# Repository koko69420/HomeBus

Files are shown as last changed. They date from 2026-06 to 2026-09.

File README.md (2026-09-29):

<p align="center">
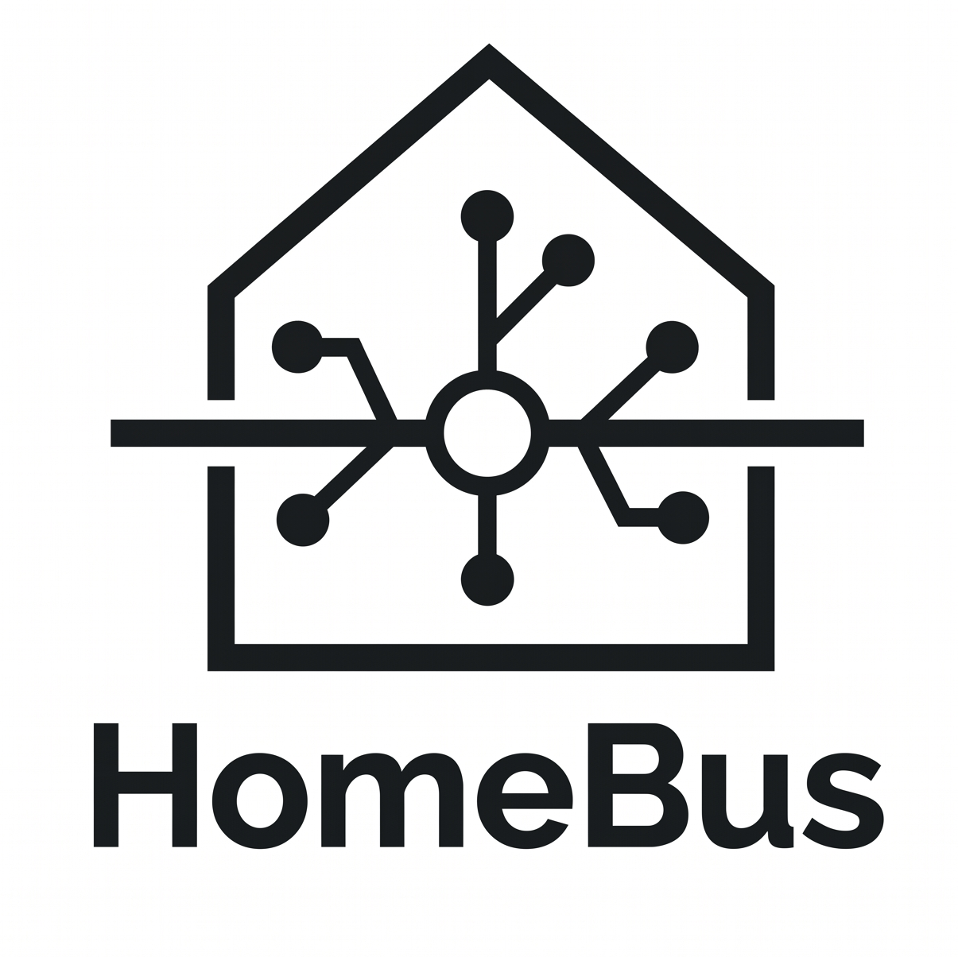
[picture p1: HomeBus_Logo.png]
HomeBus Logo
  
</p>

<h1 align="center">HomeBus</h1>

<p align="center">
  <strong>A deterministic, hard-wired distributed home automation platform built on 32-bit RISC-V microcontrollers, full-duplex RS-422 differential networking, centralized 24V DC power distribution, and native Home Assistant integration.</strong>
</p>

<p align="center">
  <a href="#system-architecture">Architecture</a> •
  <a href="#hierarchical-documentation">Documentation Map</a> •
  <a href="#hardware-overview">Hardware</a> •
  <a href="#protocol--firmware">Protocol & Firmware</a> •
  <a href="#repository-structure">Repository Structure</a> •
  <a href="#getting-started--toolchain">Getting Started</a>
</p>

---

## Overview & Motivation

Modern smart homes face severe reliability degradation when relying on congested 2.4 GHz wireless networks (Wi-Fi, Zigbee, Bluetooth). RF interference, wireless mesh packet dropouts, battery maintenance for wall sensors, and high-latency cloud dependencies undermine home automation dependability.

**HomeBus** solves this by delivering an industrial-grade, hard-wired residential infrastructure:
- **Full-Duplex RS-422 Differential Signaling**: Non-blocking serial communications operating at high baud rates without bus collision arbitration.
- **Centralized 24V DC Power Distribution**: Power and high-speed data are distributed over a single multi-conductor cable (CAT5e), eliminating failure-prone miniature AC-DC supplies inside cramped wall flush boxes.
- **Hardware/Logical Decoupling**: Wall switches trigger 32-bit logical device endpoints (`0xRRTTDDDD`). Physical hardware nodes (identified via 8-bit DIP switches) can be re-routed, replaced, or bridged to third-party devices (such as Tuya or Zigbee) without modifying wall switch wiring or node code.
- **Room-Level Gateway Segmentation**: Dual-transceiver gateway nodes divide the physical network into isolated room segments, insulating the central backbone from local switch traffic and safeguarding against bus-wide faults.
- **Fail-Safe Dual-Slot OTA Updates**: Permanent bootloader with ping-pong application flash partitions and automatic health verification rollbacks.

---

## System Architecture

```mermaid
flowchart TD
    subgraph Central ["Central Controller & Power Supply"]
        HA["Home Assistant Controller\n(Logical Address: 0xFFFF)\nMQTT / HomeBus Integration"]
        PSU["Central 24V 5A Industrial SMPS\n(DIN-Rail Mounted)"]
    end

    subgraph Backbone ["Backbone Bus (24V DC + RS-422 Full-Duplex)"]
        GW1["Gateway Node — Room 1\n(Dual MAX491 + EEPROM)"]
        GW2["Gateway Node — Room 2\n(Dual MAX491 + EEPROM)"]
    end

    subgraph Room1 ["Room 1 Sub-Bus (Isolated RS-422 + 24V Rail)"]
        BN1["Base Node\n(In-Wall Relays & Wall Switches)"]
        FN1["Fan Controller Node\n(AC Phase Control & Current Sense)"]
        SN1["Auxiliary Sensor Daughterboard\n(Presence / Temp / Lux)"]
    end

    subgraph Room2 ["Room 2 Sub-Bus (Isolated RS-422 + 24V Rail)"]
        BN2["Base Node\n(Multi-Channel Relay Actuator)"]
        FN2["Fan Controller Node\n(Ceiling Fan Speed)"]
    end

    HA <-->|RS-422 Backbone| GW1
    HA <-->|RS-422 Backbone| GW2
    PSU -->|24V Power Bus| GW1
    PSU -->|24V Power Bus| GW2

    GW1 <-->|Isolated Sub-Bus| BN1
    GW1 <-->|Isolated Sub-Bus| FN1
    GW1 <-->|Isolated Sub-Bus| SN1

    GW2 <-->|Isolated Sub-Bus| BN2
    GW2 <-->|Isolated Sub-Bus| FN2
```

---

## Hierarchical Documentation

The HomeBus documentation is hierarchically organized to provide deep technical detail at every layer while maintaining clean separation of concerns:

```text
README.md (Master Root)
├── Hardware/README.md (Hardware Subsystem Overview)
│   ├── base_node/README.md (In-Wall Actuator & Switch Interface)
│   ├── Gateway_node/README.md (Dual-Transceiver Room Segmentation Router)
│   ├── Fan_Controller_node/README.md (AC Phase-Angle Fan Speed Controller)
│   └── Expanders/README.md (Prototyping Adapters & Footprint Breakouts)
└── Firmware/README.md (Firmware & Protocol Specification v0.1)
```

### Direct Documentation Links

| Layer | Subsystem / Component | Key Documentation Topics | Link |
| :--- | :--- | :--- | :--- |
| **Subsystem** | **Hardware Platform** | 24V Bus power distribution, RS-422 differential signaling, SM712 surge protection, complete Bill of Materials (BOM), KiCad custom symbol & footprint libraries. | [Hardware Subsystem Overview](Hardware/README.md) |
| **Component** | **Base Node** | In-wall multi-channel relay actuator, 74HC165 switch shift register, CH32X033 TSSOP-20 pinouts (Dev vs Prod), 3D production renders, manufacturing schematics. | [Base Node README](Hardware/base_node/README.md) |
| **Component** | **Gateway Node** | Dual MAX491 transceivers, CAT24C256 I2C EEPROM routing tables, traffic monitoring LEDs, dedicated development breakout board. | [Gateway Node README](Hardware/Gateway_node/README.md) |
| **Component** | **Fan Controller Node** | H11AA1 zero-crossing detection, HCPL-3120 isolated gate drive, B2415S isolated DC-DC, KIA7N65H solid-state AC switching, active stall threshold protection. | [Fan Controller README](Hardware/Fan_Controller_node/README.md) |
| **Component** | **Expanders** | SMD prototyping daughterboards converting SOIC-14 (MAX491), SOIC-16 (74HC165), and TSSOP-20 (CH32X033) to standard 2.54 mm breadboard headers. | [Expanders README](Hardware/Expanders/README.md) |
| **Subsystem** | **Firmware & Protocol** | 32-bit Logical Device Addresses (`0xRRTTDDDD`), 8-bit Physical Node IDs, Control and Telemetry packet structures, Sensor Types, dual-slot ping-pong OTA bootloader. | [Firmware & Protocol README](Firmware/README.md) |

---

## Hardware Overview

### Base Node Production Renders

| Front View (Component Layout) | Back View (Connector & Power Rail) |
| :---: | :---: |
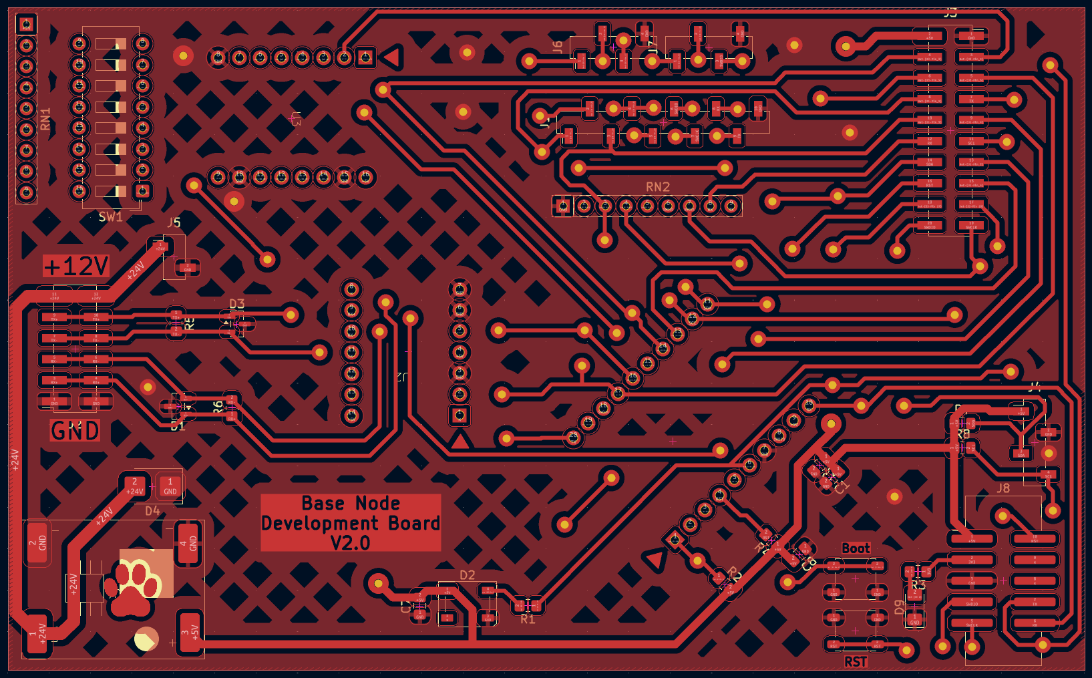
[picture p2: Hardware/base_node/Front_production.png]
HomeBus Base Node Front
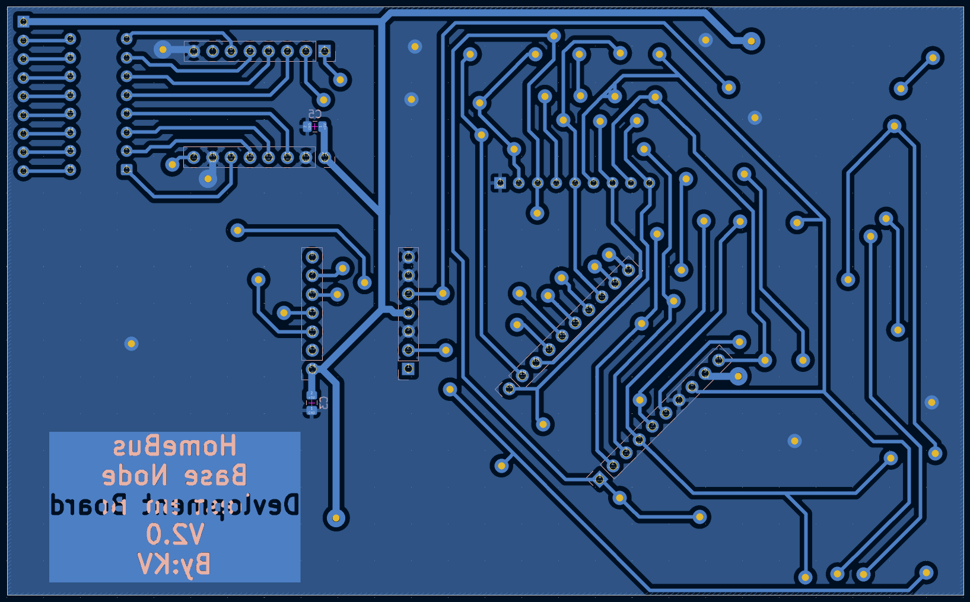
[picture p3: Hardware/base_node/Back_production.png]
HomeBus Base Node Back
|  |  |

### Core Hardware Specifications
- **Processing Core**: WCH `CH32X033F8P6` (32-bit QingKe RISC-V V4C core @ 48 MHz, 62 KB Flash, 20 KB SRAM).
- **Physical Layer Transceiver**: Maxim `MAX491CSD` / `MAX491ESD` (SOP-14 full-duplex differential transceiver).
- **Bus Power Regulation**: Monolithic Power Systems `MP1584EN` (high-frequency buck converter, 24V In to 5V DC Out @ 3A).
- **Transient Protection**: ProTek `SM712` asymmetrical bidirectional TVS diode array (-7V to +12V) on all RS-422 differential pairs.
- **Input Multiplexing**: NXP / TI `74HC165D` 8-bit PISO shift register for parallel sampling of physical wall switches and the 8-bit DIP switch.
- **Visual Feedback**: Xinglight `XL-1010RGBC` (`WS2812B-1010`) addressable RGB LED for link status and diagnostics.
- **Detailed Component Records**: Complete component pricing, supplier links, and quantities are tracked in [`Hardware/BOM Home automation.xlsx`](Hardware/BOM%20Home%20automation.xlsx).

---

## Protocol & Firmware Highlights

For the full technical protocol specification, see the [Firmware & Protocol Documentation](Firmware/README.md).

### Logical vs. Physical Addressing
- **Physical Node ID (8-bit)**: Set on the hardware DIP switch (1–255). Used strictly for commissioning, OTA updates, diagnostics, and telemetry.
- **Logical Device Address (32-bit)**: Structured as `0xRRTTDDDD`:
  - `RR`: Room ID (e.g. `0x01` Living Room)
  - `TT`: Device Type (e.g. `0x01` Relay, `0x04` Fan)
  - `DDDD`: Device Unique Index
  - `0xFFFF`: Home Assistant Central Controller
- *Input nodes never transmit physical node IDs—wall switches target logical devices, allowing seamless device migration and third-party bridging.*

### Dual-Slot Failsafe OTA Bootloader
Each node partitions its 62 KB flash into a permanent bootloader (8 KB), Application Slot A (24 KB), Application Slot B (24 KB), and Non-Volatile Config (8 KB). Firmware updates are verified with 16-bit CRC before switching execution slots, with automated fallback if health confirmation is not returned.

---

## Repository Structure

```text
HomeBus/
├── Datasheets/                                # Technical datasheets for all ICs and sensors
│   ├── 7N65H.PDF                              # KEC 650V 7A Power MOSFET
│   ├── CH32X035.pdf                           # WCH RISC-V Microcontroller Series
│   ├── HCPL3120.pdf                           # Broadcom High-CMR Gate Driver
│   ├── HWCT-5A(5mA).pdf                       # AC Current Transformer
│   ├── MCP6001.pdf                            # Microchip Rail-to-Rail Op-Amp
│   ├── RGB_LED_C5349936.pdf                   # XL-1010RGBC Addressable RGB LED
│   └── vo3120.pdf                             # Vishay High-Speed Optocoupler
├── Firmware/                                  # Firmware subsystem and protocol specifications
│   ├── HomeBus Protocol Specification v0.1.docx # Upstream design document
│   └── README.md                              # Complete protocol specification & packet format guide
├── Hardware/                                  # Hardware design, schematics, and layouts
│   ├── BOM Home automation.xlsx               # Comprehensive Bill of Materials with pricing & links
│   ├── Pin Allocations.xlsx                   # MCU GPIO allocation reference (Dev vs Prod)
│   ├── README.md                              # Hardware subsystem overview & bus topology
│   ├── base_node/                             # In-wall actuator & switch node PCB (Revisions 1 to 4)
│   │   ├── Basenode_gerber/                   # Industrial fabrication Gerbers and drill maps
│   │   ├── Front_production.png               # 3D PCB front render
│   │   ├── Back_production.png                # 3D PCB back render
│   │   ├── Schematic_manufacturing.pdf        # Production schematic plot
│   │   └── README.md                          # Base Node component documentation
│   ├── Gateway_node/                          # Segmentation bridge & routing node
│   │   ├── Gateway_node_dev-board/            # Prototyping development board layout & plots
│   │   └── README.md                          # Gateway Node component documentation
│   ├── Fan_Controller_node/                   # AC phase-angle fan speed controller PCB
│   │   └── README.md                          # Fan Controller Node component documentation
│   └── Expanders/                             # SMD to 2.54mm breadboard prototyping adapters
│       └── README.md                          # Expanders component documentation
├── lib/                                       # KiCad custom symbol, footprint, and 3D libraries
│   ├── 3D_models/                             # Mechanical STEP models
│   ├── HomeBus.kicad_mod/                     # Footprint library (.kicad_mod)
│   └── HomeBus.kicad_sym                      # Schematic symbol library
├── HomeBus_Logo.png                           # Raster logo asset
├── HomeBus_Logo.svg                           # Vector logo asset
└── README.md                                  # Root documentation hub
```

---

## Getting Started & Toolchain

### Hardware Design (EDA)
- **EDA Suite**: [KiCad 7.x / 8.x](https://www.kicad.org/)
- **Opening Projects**: Double-click `.kicad_pro` inside any node directory (e.g. `Hardware/base_node/base_node_clad_v2.kicad_pro`).
- **Libraries**: All custom components are pre-configured in project-relative paths pointing to `lib/HomeBus.kicad_sym` and `lib/HomeBus.kicad_mod/`.

### Firmware Development & Debugging
- **Core Architecture**: QingKe 32-bit RISC-V V4C (`rv32imac`).
- **Toolchain**: `riscv-none-elf-gcc` / MounRiver Studio / OpenOCD for WCH.
- **Hardware Debugger**: [WCH-LinkE](https://www.wch-ic.com/products/WCH-Link.html) programmer/debugger connected via 1-wire SWD (`SWDIO`, `SWCLK`, `GND`, `3V3`).

---

## License & Authorship

All hardware designs, schematics, PCB artwork, and protocol specifications are authored by **Kaustubh** (`koko69420`). All rights reserved.

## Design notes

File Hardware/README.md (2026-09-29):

# HomeBus Hardware Subsystem

The **HomeBus Hardware Subsystem** encompasses the schematics, PCB layouts, electrical interfaces, and component specifications that power the HomeBus automation platform. Built on the 32-bit RISC-V `CH32X033F8P6` microcontroller, HomeBus employs a robust wired topology combining a centralized 24V DC power rail with full-duplex RS-422 differential serial communications.

---

## Physical Bus Architecture & Power Distribution

HomeBus uses standard structured cabling (CAT5e / multi-conductor shielded cable) terminated into pluggable terminal blocks (`XY2500` 6-pin connectors):

```mermaid
flowchart LR
    subgraph PowerStation ["Central Power Supply"]
        PSU["24V 5A Industrial SMPS\n(Centralized DIN-Rail / Cabinet)"]
    end

    subgraph BusCable ["6-Conductor HomeBus Cable (CAT5e / Shielded)"]
        direction TB
        VBUS["+24V DC Power (Wire 1)"]
        GND["GND / Return (Wire 2)"]
        TXP["TX+ Differential Line (Wire 3)"]
        TXN["TX- Differential Line (Wire 4)"]
        RXP["RX+ Differential Line (Wire 5)"]
        RXN["RX- Differential Line (Wire 6)"]
    end

    subgraph Node ["Connected HomeBus Node"]
        BUCK["MP1584EN Step-Down\n(24V -> 5V Logic)"]
        TVS["SM712 TVS Array\n(-7V to +12V)"]
        XCVR["MAX491 Transceiver\n(RS-422 Full-Duplex)"]
        MCU["CH32X033F8P6\n(32-bit RISC-V Core)"]
    end

    PSU --> VBUS
    PSU --> GND
    VBUS --> BUCK --> MCU
    GND --> Node
    TXP & TXN & RXP & RXN <--> TVS <--> XCVR <--> MCU
```

### Key Electrical Principles
1. **Centralized 24V DC Distribution**: Eliminates bulky and fire-prone AC-to-DC converters inside small wall boxes. Centralizing mains power conversion inside a well-ventilated enclosure ensures high efficiency and simplified battery backup (UPS) integration.
2. **Local Buck Regulation**: Each node integrates an `MP1584EN` high-frequency switching buck module stepping down 24V DC to 5V DC at up to 3A, easily powering the MCU, RGB status LEDs, sensors, and external relay coils without thermal throttling.
3. **Full-Duplex Differential Signaling (RS-422)**: Utilizing dedicated differential pairs for transmit (`TX±`) and receive (`RX±`) driven by Maxim `MAX491` transceivers allows non-blocking, bidirectional communication.
4. **Transient & Surge Protection**: Every differential line interface is clamped by `SM712` asymmetrical TVS diodes designed specifically for RS-422 transceivers, safeguarding against electrostatic discharge (ESD up to ±15 kV) and induced power line transients.

---

## Node Modules & Component Directory

The HomeBus hardware platform is partitioned into specialized node modules:

| Module | Location | Primary Role & Description | Documentation Link |
| :--- | :--- | :--- | :--- |
| **Base Node** | [`base_node/`](base_node/) | In-wall multi-channel actuator and wall-switch sensor interface fitting standard electrical backboxes. | [Base Node README](base_node/README.md) |
| **Gateway Node** | [`Gateway_node/`](Gateway_node/) | Dual-transceiver bridge providing room-level bus segmentation, EEPROM routing tables, and traffic diagnostics. | [Gateway Node README](Gateway_node/README.md) |
| **Fan Controller Node** | [`Fan_Controller_node/`](Fan_Controller_node/) | Solid-state AC speed controller featuring zero-crossing sync (`H11AA1`), isolated gate drive (`HCPL-3120`), and stall prevention. | [Fan Controller README](Fan_Controller_node/README.md) |
| **Expanders** | [`Expanders/`](Expanders/) | Prototyping breakout adapters converting SMD footprints (SOIC-14, SOIC-16, TSSOP-20) to 2.54mm breadboard headers. | [Expanders README](Expanders/README.md) |

---

## Bill of Materials (BOM) Summary

Extracted directly from project engineering records ([`BOM Home automation.xlsx`](BOM%20Home%20automation.xlsx)):

| Category | Component Part | Package | Description | Key Specifications |
| :--- | :--- | :--- | :--- | :--- |
| **Processing** | WCH `CH32X033F8P6` | TSSOP-20 | RISC-V Microcontroller | 48 MHz QingKe V4C, 62 KB Flash, 20 KB SRAM |
| **Networking** | Maxim `MAX491CSD` / `MAX491ESD` | SOP-14 | RS-422 Transceiver | Full-duplex differential transceiver |
| **Input Expansion** | NXP / TI `74HC165D` | SOP-16 | Shift Register | 8-bit Parallel-In Serial-Out (PISO) |
| **Power Buck** | Monolithic Power `MP1584EN` | Module | Step-Down Buck Converter | 24V to 5V DC, 3A max output |
| **Bus Protection**| ProTek `SM712` / `PSM712` | SOT-23 | TVS Diode Array | Asymmetrical (-7V / +12V) RS-422 protection |
| **Status LED** | Xinglight `XL-1010RGBC` (`WS2812B`) | SMD-1010 | Addressable RGB LED | Single-wire data protocol |
| **Zero Crossing** | Vishay `H11AA1` | DIP-6 | AC Optocoupler | Bidirectional input, transistor output |
| **Gate Driver** | Broadcom `HCPL-3120` / `VO3120` | DIP-8 / SOP-8| Optocoupled Gate Driver | 2.5A peak drive, CMR > 15 kV/µs |
| **Isolated DC-DC**| Hi-Link `B2415S-1WR3` | SIP-4 | Isolated Power Module | 24VDC In / 15VDC Out, 1W isolated |
| **AC Switching** | KEC `KIA7N65H` | TO-220F | N-Channel Power MOSFET | 650V, 7A, $R_{DS(on)} = 1.4\ \Omega$ |
| **Current Sense** | `ZHT103` / `HWCT-5A` | Through-Hole | Current Transformer | 5A primary / 5mA secondary |
| **Amplifier** | Microchip `MCP6001` | SOT-23-5 | Operational Amplifier | Rail-to-rail I/O, 1 MHz GBW |
| **Routing Memory**| Microchip `AT24C256C` / `CAT24C256` | SOIC-8 | I2C Serial EEPROM | 256 Kbit (32 KByte), 1 MHz I2C |
| **Mains Varistor**| `10D471K` | Disc 10mm | Metal Oxide Varistor | 470V clamping, 2.5 kA surge |
| **Mains Fuse** | `2010T1A250V` | Radial / 2010 | Slow-Blow Micro Fuse | 1A, 250V AC time-lag |
| **Bus Connector** | `XY2500` Pair (6-Pin) | 5.08mm Pitch | Pluggable Screw Terminal | Rated 300V / 10A, polarized locking |

---

## Custom KiCad EDA Libraries

All schematic symbols, PCB footprints, and 3D CAD assets are maintained in [`lib/`](../lib/):
- **Symbol Library**: [`lib/HomeBus.kicad_sym`](../lib/HomeBus.kicad_sym) — Customized symbols for CH32X033, MP1584 module, optocouplers, and connectors.
- **Footprint Library**: [`lib/HomeBus.kicad_mod/`](../lib/HomeBus.kicad_mod/) — Custom footprints for compact SMD assembly:
  - `XL-1010RGBC-WS2812B.kicad_mod` (SMD-1010 addressable LED)
  - `MP1584 Module.kicad_mod` (DC-DC step-down footprint)
  - `TSSOP-20-2.54_expander.kicad_mod`, `SOIC-16-2.54_expander.kicad_mod`, `SOIC-14-2.54_expander.kicad_mod`
  - `SW_SPST_PTS647_Sx38.kicad_mod` (Tactile push switches)
  - `ZHT103_CT103_2pin.kicad_mod` (Current transformer)
- **3D STEP Models**: [`lib/3D_models/`](../lib/3D_models/) — Includes mechanical CAD models (e.g. `XL-1010RGBC-WS2812B--3DModel-STEP-510211.STEP`).

---

## Navigation

- [↑ HomeBus Root Documentation](../README.md)
- [Base Node Documentation →](base_node/README.md)
- [Gateway Node Documentation →](Gateway_node/README.md)
- [Fan Controller Node Documentation →](Fan_Controller_node/README.md)
- [Expander Daughterboards Documentation →](Expanders/README.md)
- [Firmware & Protocol Specification →](../Firmware/README.md)

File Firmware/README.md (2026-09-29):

# HomeBus Firmware & Protocol Specification (v0.1)

The **HomeBus Protocol** is a deterministic, distributed home automation communication protocol specifically designed for full-duplex RS-422 wired serial networks, 24V centralized power distribution, and WCH CH32X033 32-bit RISC-V nodes integrated with **Home Assistant**.

---

## Design Philosophy: Hardware vs. Logical Decoupling

The central architectural innovation of HomeBus is the complete decoupling between **Physical Hardware Nodes** and **Logical Controllable Devices**:

```mermaid
flowchart TD
    subgraph Inputs ["Input Devices (Wall Plates)"]
        SW1["Switch 1\n(Targets: 0x01010001)"]
        ENC1["Rotary Encoder\n(Targets: 0x01040001)"]
    end

    subgraph Network ["HomeBus RS-422 Bus / Gateways"]
        GW["Gateway Router\n(Address Translation)"]
    end

    subgraph PhysicalEndpoints ["Execution Targets"]
        RLY["Base Node (Node ID 42)\nRelay 1 = 0x01010001"]
        FAN["Fan Node (Node ID 73)\nCeiling Fan = 0x01040001"]
        TUYA["Tuya / Wi-Fi Bridge\nLight = 0x01010002"]
    end

    SW1 --> GW
    ENC1 --> GW
    GW --> RLY
    GW --> FAN
    GW -.-> TUYA
```

### 1. Physical Node
A **Node** represents a physical hardware device connected to the bus (e.g. Base Node, Fan Controller Node, Gateway Node, Sensor Node).
- Every node has an 8-bit **Node ID** (1–255) configured via an onboard 8-position SPST DIP switch.
- **Node IDs are strictly reserved for**:
  - Initial bus commissioning and discovery
  - Over-the-Air (OTA) firmware deployment
  - Device diagnostic pinging and hardware telemetry
  - Network topology mapping
- *Node IDs are never used for normal device actuation or user commands.*

### 2. Logical Device
A **Device** represents a logical controllable endpoint (e.g., *Living Room Chandelier*, *Master Bedroom Ceiling Fan*, *Kitchen Under-Cabinet LED*).
- Each device possesses a 32-bit **Logical Device Address**:
  $$\text{Address} = \mathtt{0xRRTTDDDD}$$
  - **`RR` (8-bit)**: Room Identifier (e.g., `0x01` Living Room, `0x02` Master Bedroom).
  - **`TT` (8-bit)**: Device Type category.
  - **`DDDD` (16-bit)**: Device Unique Index within that room and type.
  - **`0xFFFF`**: Reserved broadcast address for the **Central Controller (Home Assistant)**.

#### Device Decoupling Advantage
Wall switches and input nodes only transmit commands targeting a **Logical Device Address** (`0xRRTTDDDD`). The input switch has no knowledge of whether the endpoint is actuated by an onboard relay on Node 42, an external smart dimmer, or a bridged Tuya Wi-Fi plug. If hardware is replaced or re-wired, no switch configurations need to be changed—only the gateway mapping table is updated.

---

## Packet Specifications

All HomeBus communications use full-duplex RS-422 packet framing. Every packet incorporates a 16-bit CRC checksum. Corrupted packets are immediately dropped without blocking the transceiver.

### 1. Control Packet (Device Action)
Used to actuate a logical device. The packet transmits only the target address and action; source information is omitted because actuators act purely on destination logic.

```text
+-----------------------+---------+----------------+------------------+---------+
|  Destination Address  | Command | Payload Length |  Payload Bytes   |  CRC16  |
|        (32-bit)       | (8-bit) |    (8-bit)     |     (N bytes)    | (16-bit)|
+-----------------------+---------+----------------+------------------+---------+
```

#### Supported Control Commands

| Code | Command Identifier | Payload Schema | Functional Description |
| :---: | :--- | :--- | :--- |
| `0x01` | `SET_STATE` | `0x00` (OFF) / `0x01` (ON) | Forces relay or device to explicit ON or OFF state. |
| `0x02` | `TOGGLE` | None (Length = 0) | Inverts the current output state. |
| `0x03` | `SET_PERCENT` | `0` to `100` (1 byte uint8) | Sets dimmer level or fan speed percentage. |
| `0x04` | `INCREASE_PERCENT`| Delta uint8 (`+1` to `+100`) | Increments output level by the specified percentage. |
| `0x05` | `DECREASE_PERCENT`| Delta uint8 (`-1` to `-100`) | Decrements output level by the specified percentage. |
| `0x06` | `SET_BRIGHTNESS` | `0` to `255` (1 byte uint8) | Sets absolute PWM light intensity. |
| `0x07` | `SET_COLOR` | `R`, `G`, `B` (3 bytes) | Configures RGB light color. |
| `0x08` | `SET_PATTERN` | Pattern ID (uint8) + Rate | Triggers pre-programmed lighting pattern or animation. |
| `0x09` | `IDENTIFY` | Duration in seconds (uint8) | Rapidly flashes node status LED for physical device identification. |

### 2. Telemetry Packet (Sensor Data & Status)
Transmitted by sensor nodes, power meters, and actuators to report real-time readings to the Home Assistant controller (`0xFFFF`).

```text
+-----------------------+---------+-------------+----------------+---------------+---------+
| Destination (0xFFFF)  | Node ID | Sensor Type | Payload Length | Payload Bytes |  CRC16  |
|        (32-bit)       | (8-bit) |   (8-bit)   |    (8-bit)     |   (N bytes)   | (16-bit)|
+-----------------------+---------+-------------+----------------+---------------+---------+
```

#### Supported Sensor Types

| Type Code | Sensor Type | Units / Encoding | Description |
| :---: | :--- | :--- | :--- |
| `0x01` | **Temperature** | IEEE 754 Float32 / Int16 (°C $\times 10$) | Ambient temperature (AHT21 / BME680). |
| `0x02` | **Humidity** | Float32 / Int16 (%RH $\times 10$) | Relative humidity (AHT21 / BME680). |
| `0x03` | **Presence** | Boolean / Distance (cm) | Millimeter-wave motion sensor (HLK-LD2420 / LD2402). |
| `0x04` | **Light Level** | Lux (uint16 / Float32) | Ambient illuminance (BH1750 / GL5528). |
| `0x05` | **Current** | Amperes RMS (Float32 / Int16 mA)| AC line current via HWCT-5A / ZHT103 transformer. |
| `0x06` | **Active Power** | Watts (Float32 / Int16 W) | Real-time power consumption. |
| `0x07` | **Voltage** | Volts RMS (Float32) | AC mains line voltage. |
| `0x08` | **Total Energy** | Kilowatt-hours (Float32 kWh) | Accumulated energy consumption. |
| `0x09` | **Fan RPM** | Revolutions Per Minute (uint16)| Tachometer feedback from inductive fan motor. |
| `0x0A` | **NTC Temperature**| °C (Int16 $\times 10$) | Internal PCB / MOSFET heatsink thermistor. |

---

## Telemetry Reporting Policies

To optimize bus utilization without missing critical events:

1. **Event-Driven Reporting**:
   - Applied to: Switch toggles, rotary encoder turns, millimeter-wave presence detection, door/window contacts.
   - Transmission Policy: Transmitted **immediately** upon state change detection.
2. **Periodic Telemetry Reporting**:
   - Applied to: Environmental sensors (temperature, humidity, atmospheric pressure, light level) and electrical metrics (RMS current, voltage, accumulated energy).
   - Transmission Policy: Transmitted at regular intervals (user-configurable between **30 seconds** and **300 seconds**).

---

## Gateway Routing & Segmentation

Gateway nodes operate between the primary **Backbone Bus** and local **Room Sub-Buses**:
- **Dual Transceivers**: Each Gateway operates two isolated `MAX491` transceivers (Trunk and Room).
- **Packet Filtering**: Packets with local room targets are contained within the room, preventing backbone saturation.
- **Routing Memory**: Gateway maintains local translation tables in onboard 256-Kbit I2C EEPROM (`CAT24C256` / `AT24C256C`).
- **Bridge Support**: If a logical device address is mapped to an external protocol (e.g. Tuya Wi-Fi device), the Gateway issues the bridge command outward.

---

## Commissioning Workflow

```mermaid
sequenceDiagram
    autonumber
    actor Tech as Installer
    participant Node as New Hardware Node
    participant GW as Gateway Node
    participant HA as Home Assistant

    Tech->>Node: Set 8-bit DIP Switch (e.g. Node ID = 42)
    Tech->>Node: Connect 24V RS-422 Bus Cable
    Node->>Node: Power-On Self Test (POST)
    Node->>GW: Broadcast Commission Request (Node ID 42, Capabilities)
    GW->>HA: Forward Commission Request
    alt Node ID Recognized in DB
        HA->>GW: Transmit Stored Configuration & Logical Addresses
        GW->>Node: Forward Configuration
        Node-->>Tech: WS2812B Flashes Green (Bound & Restored)
    else Unknown Node ID
        HA-->>Tech: UI Prompt: New HomeBus Device Discovered
        Tech->>HA: Assign Room & Map Relay/Sensor Channels
        HA->>GW: Issue Node Binding Packet
        GW->>Node: Apply Configuration
        Node-->>Tech: WS2812B Flashes Blue (Commissioned)
    end
```

---

## Dual-Slot Failsafe OTA Deployment

All HomeBus nodes feature a permanent hardware bootloader and dual ping-pong flash partitions in the 62 KB internal flash memory of the `CH32X033F8P6`:

### Flash Memory Layout

```text
+-----------------------+ 0x0000_FFFF
| Config & Calibration  | 8 KB Non-Volatile Parameters
+-----------------------+ 0x0000_E000
| Application Slot B    | 24 KB Secondary Firmware Partition
+-----------------------+ 0x0000_8000
| Application Slot A    | 24 KB Primary Firmware Partition
+-----------------------+ 0x0000_2000
| Permanent Bootloader  | 8 KB Hardware Factory Bootloader
+-----------------------+ 0x0000_0000
```

### OTA Update Execution Sequence
1. **Download**: The central controller streams encrypted binary chunks to the inactive slot over the RS-422 bus.
2. **CRC Verification**: The bootloader verifies the 16-bit CRC checksum across the complete downloaded image.
3. **Slot Switch**: The active boot slot register in configuration flash is toggled (e.g., Slot A $\rightarrow$ Slot B).
4. **Reboot**: The MCU issues a software system reset into the new slot.
5. **Health Check**: The new firmware runs self-diagnostics and must transmit a `Health Confirmation` packet to the Gateway within 15 seconds.
6. **Automatic Rollback**: If the confirmation fails or the node watchdog triggers, the bootloader automatically reverts to the previous working slot.

---

## Navigation

- [↑ HomeBus Root Documentation](../README.md)
- [Hardware Subsystem Overview →](../Hardware/README.md)
- [Base Node Component Documentation →](../Hardware/base_node/README.md)
- [Gateway Node Component Documentation →](../Hardware/Gateway_node/README.md)
- [Fan Controller Node Component Documentation →](../Hardware/Fan_Controller_node/README.md)
- [Expander Daughterboards Documentation →](../Hardware/Expanders/README.md)

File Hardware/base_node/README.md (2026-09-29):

# HomeBus Base Node

The **HomeBus Base Node** is the primary in-wall actuator and sensor module in the HomeBus distributed automation network. Designed to fit into standard residential switch flush boxes behind wall plates, it interfaces physical toggle switches and rotary encoders with the HomeBus RS-422 serial bus while driving external relay modules to switch lights, appliances, and inductive loads.

---

## Visual Previews

### 3D Production Renders
| Front View (Component Side) | Back View (Connector Side) |
| :---: | :---: |
| HomeBus Base Node Front | HomeBus Base Node Back |

### Manufacturing Schematic
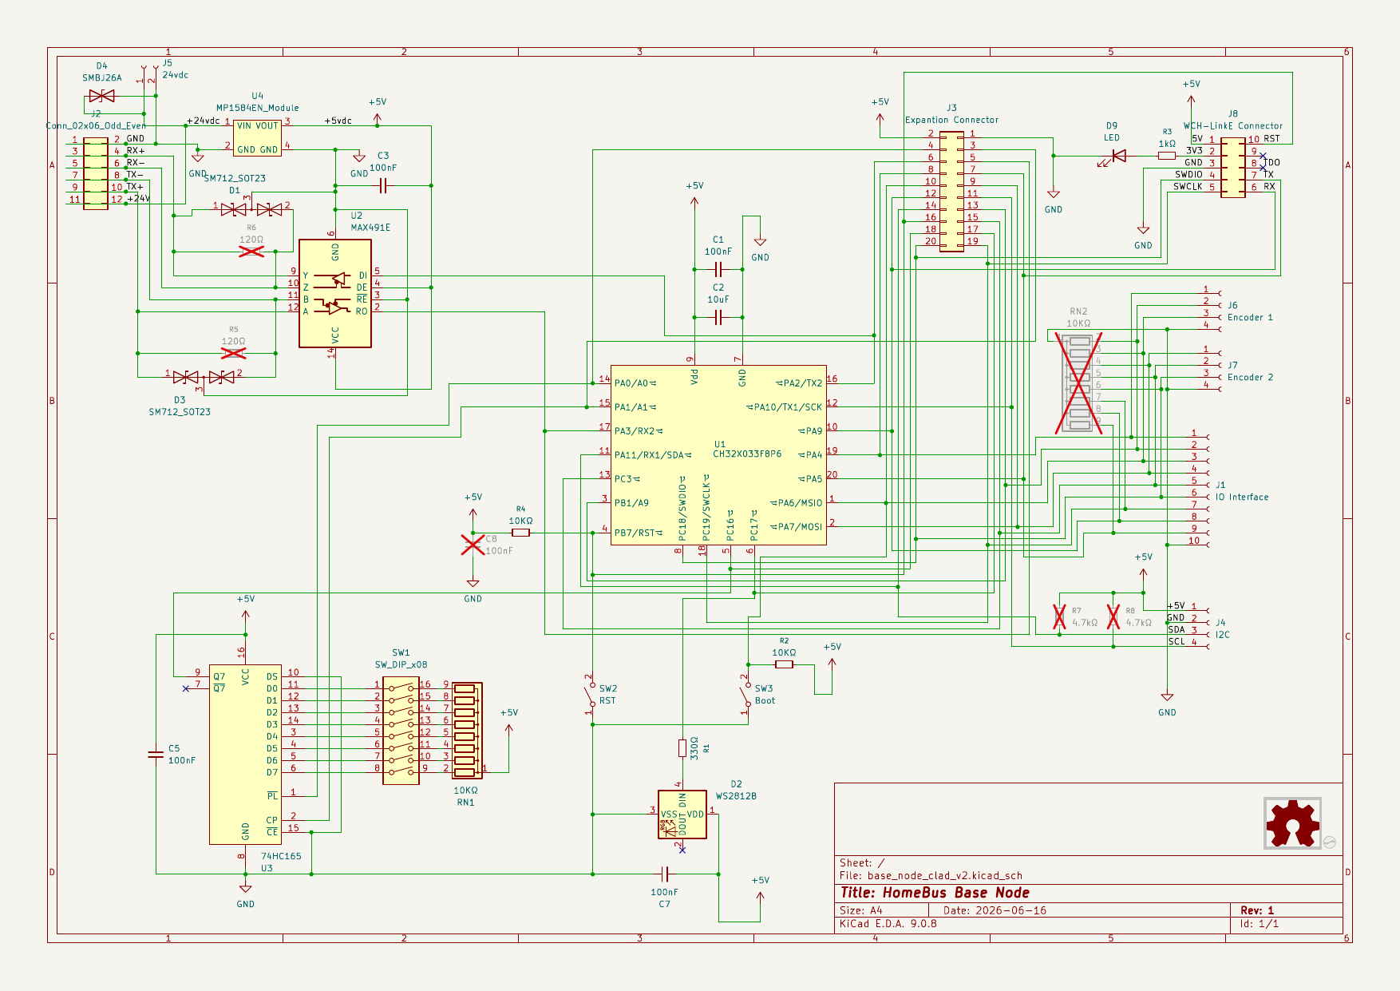
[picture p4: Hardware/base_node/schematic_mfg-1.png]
Base Node Manufacturing Schematic


---

## Hardware Architecture

```mermaid
flowchart LR
    subgraph Power ["Power Subsystem"]
        BUS_IN["24V DC Bus Rail"] --> BUCK["MP1584EN Buck Converter\n(24V -> 5V DC @ 3A)"]
        BUCK --> VDD["5V Logic Rail"]
    end

    subgraph BusInterface ["RS-422 Interface"]
        RS422["XY2500 6-Pin Bus Header\n(24V, GND, TX±, RX±)"]
        TVS["SM712 TVS Array\n(-7V to +12V Protection)"]
        XCVR["MAX491 Transceiver\n(Full-Duplex RS-422)"]
        RS422 <--> TVS <--> XCVR
    end

    subgraph Processing ["Core MCU"]
        MCU["WCH CH32X033F8P6\n(32-bit QingKe RISC-V @ 48 MHz)"]
    end

    subgraph Inputs ["Input Subsystem"]
        DIP["8-Bit DIP Switch\n(Hardware Node ID)"]
        WALL["External Wall Switches /\nRotary Encoders (JST-PH)"]
        SR["74HC165D Shift Register\n(8-bit PISO Shift Register)"]
        DIP --> SR
        WALL --> SR
    end

    subgraph Indicators ["Visual Feedback"]
        LED["WS2812B-1010 Addressable RGB LED\n(Status / Diagnostics)"]
    end

    subgraph Outputs ["Actuator Expansion"]
        EXP["IDC 2x5 Expansion Header\n(Relay Control GPIOC 1-5, 8, 9)"]
    end

    XCVR <-->|UART DI / RO| MCU
    SR -->|Serial Q7, PL_, CP| MCU
    MCU -->|Serial WS2812 Data| LED
    MCU -->|GPIO Outputs| EXP
    VDD --> MCU
    VDD --> XCVR
    VDD --> SR
```

---

## Key Hardware Components

| Subsystem | Component | Package | Function / Rationale |
| :--- | :--- | :--- | :--- |
| **Microcontroller** | WCH `CH32X033F8P6` | TSSOP-20 | QingKe 32-bit RISC-V V4C core @ 48 MHz, 62 KB Flash, 20 KB SRAM. Handles RS-422 protocol stack, switch debouncing, and relay actuation. |
| **Transceiver** | Maxim `MAX491CSD` / `MAX491ESD` | SOP-14 | High-speed, full-duplex RS-422/RS-485 differential transceiver. Allows simultaneous transmit and receive with no collision backoff. |
| **Input Multiplexer** | NXP / TI `74HC165D` | SOP-16 | 8-bit Parallel-In Serial-Out (PISO) shift register. Samples the 8-bit DIP switch and wall inputs using only 3 MCU pins (`PL_`, `CP`, `Q7`). |
| **Power Converter** | Monolithic Power `MP1584EN` | Modular Module | 3A high-frequency step-down switching buck regulator module converting centralized 24V bus power to regulated 5V system logic. |
| **Surge Protection** | ProTek `SM712` / `PSM712` | SOT-23 | Asymmetrical bidirectional TVS diode array (-7V to +12V) specifically engineered for RS-422 lines against ESD, EFT, and power transients. |
| **Status Indicator** | Xinglight `XL-1010RGBC` (`WS2812B-1010`) | SMD-1010 (1.0x1.0mm) | Ultra-compact single-wire addressable RGB LED for status indication, network link health, and commissioning feedback. |
| **Hardware ID** | 8-Position SPST DIP Switch | 2.54mm Pitch Slide | Configures physical Node ID (1–255) for commissioning, telemetry, and OTA management. |

---

## Pin Allocation Table

The Base Node assigns the 20 pins of the `CH32X033F8P6` as follows, differentiating between **Development** mode (SWD debug available) and **Production** mode (SWD pins repurposed for actuator GPIOs):

| Pin # | MCU Pin | Production Function | Development Function | Net / Description |
| :---: | :---: | :---: | :---: | :--- |
| **1** | PA0 / PC3 | `GPIOC 3` | `Boot Switch` | Actuator Output 3 in Production; Bootloader entry trigger in Development |
| **2** | PA1 / PC4 | `GPIOC 4` | `GPIOC 4` | Actuator Output 4 / Relay drive line |
| **3** | PA2 / PC2 | `GPIOC 2` | `GPIOC 2` | Actuator Output 2 / Relay drive line |
| **4** | NRST | `RST` | `RST` | Hardware Reset line (active low, with pull-up) |
| **5** | PB0 / PC0 | `HC165 Q7` | `HC165 Q7` | Shift Register Serial Data Out (MISO stream to MCU) |
| **6** | PB1 | `Neopixel` | `Neopixel` | High-speed single-wire NRZ serial data stream to WS2812B LED |
| **7** | VSS | `GND` | `GND` | System Ground (0V reference) |
| **8** | PB2 / PC6 | `GPIOC 6` | `SWDIO` | Actuator Output 6 in Production; WCH SWD Debug Data in Development |
| **9** | VDD | `VDD` | `VDD` | Logic Supply Rail (+5V DC from MP1584EN) |
| **10** | PB3 / PC8 | `GPIOC 8` | `SWD RX` | Actuator Output 8 in Production; Debug UART RX in Development |
| **11** | PB6 | `I2C SDA` | `I2C SDA` | I2C Serial Data line for auxiliary sensor daughterboards |
| **12** | PB7 | `I2C SCL` | `I2C SCL` | I2C Serial Clock line for auxiliary sensor daughterboards |
| **13** | PB4 / PC5 | `GPIOC 5` | `GPIOC 5` | Actuator Output 5 / Relay drive line |
| **14** | PB5 | `HC165 PL_` | `HC165 PL_` | 74HC165 Asynchronous Parallel Load (active low) |
| **15** | PB8 | `HC165 CP` | `HC165 CP` | 74HC165 Shift Register Clock Pulse |
| **16** | PB10 | `MAX491 DI` | `MAX491 DI` | RS-422 Driver Input (MCU UART TX to RS-422 differential bus) |
| **17** | PB11 | `MAX491 RO` | `MAX491 RO` | RS-422 Receiver Output (RS-422 differential bus to MCU UART RX) |
| **18** | PB9 / PC7 | `GPIOC 7` | `SWCLK` | Actuator Output 7 in Production; WCH SWD Clock in Development |
| **19** | PA3 / PC1 | `GPIOC 1` | `GPIOC 1` | Actuator Output 1 / Relay drive line |
| **20** | PA4 / PC9 | `GPIOC 9` | `SWD TX` | Actuator Output 9 in Production; Debug UART TX in Development |

---

## Revision History

1. **`base_node` (v1.0)**: Initial prototype layout. Used orthogonal 45° routing and tested basic connectivity between the CH32X033 and MAX491.
2. **`base_node-rounded` (v1.1)**: Experimental PCB layout with circular/curved track fillets using KiCad round-tracks plugin for aesthetic evaluation and high-speed trace continuity.
3. **`base_node_clad` (v1.2)**: Added continuous solid copper pour cladding across top and bottom layers, significantly reducing ground impedance and improving EMI containment in high-noise AC environments.
4. **`base_node_clad_v2` (v2.0 - Production)**:
   - Optimized high-voltage isolation creepage and clearance distances between mains-connected lines and low-voltage logic.
   - Refined component clearances for compact hand-soldering and reflow stenciling.
   - Added reinforced thermal pads and teardrop transitions on signal vias.
   - Verified Gerber generation ready for industrial fabrication under [`Basenode_gerber/`](Basenode_gerber/).

---

## Manufacturing & Assembly

- **Gerber Files**: Ready-to-manufacture archives are stored in [`Basenode_gerber/base_node.zip`](Basenode_gerber/base_node.zip).
- **PCB Fabrication Parameters**:
  - Layers: 2-layer FR-4
  - Board Thickness: 1.6 mm
  - Copper Weight: 1 oz (35 µm)
  - Surface Finish: HASL Lead-Free / ENIG recommended
  - Minimum Trace / Space: 0.2 mm / 0.2 mm
  - Solder Mask: Blue / Matte Black
  - Silkscreen: White
- **Fabrication Plots**:
  - Top Copper: [`base_node_clad_v2-F_Cu.pdf`](base_node_clad_v2-F_Cu.pdf)
  - Bottom Copper: [`base_node_clad_v2-B_Cu.pdf`](base_node_clad_v2-B_Cu.pdf)
  - Edge Cuts / Outline: [`base_node_clad_v2-Edge_Cuts.pdf`](base_node_clad_v2-Edge_Cuts.pdf)

---

## Navigation

- [← Hardware Subsystem Overview](../README.md)
- [↑ HomeBus Root Documentation](../../README.md)
- [Gateway Node Documentation →](../Gateway_node/README.md)
- [Fan Controller Node Documentation →](../Fan_Controller_node/README.md)
- [Expander Daughterboards Documentation →](../Expanders/README.md)
- [Firmware & Protocol Specification →](../../Firmware/README.md)

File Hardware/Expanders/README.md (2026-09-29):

# HomeBus Expanders & Prototyping Adapters

The **HomeBus Expanders** module provides a set of standardized breakout adapters and prototyping daughterboards engineered for rapid bench testing, firmware development, in-circuit emulation, and breadboard interfacing of high-density surface-mount devices (SMD) used throughout the HomeBus ecosystem.

---

## Visual Previews

### Top Copper PCB Layout
The expander board brings high-density SMD IC footprints out to standard 2.54 mm (0.1") dual-row and single-row pin headers:

| Expander Breakout PCB (Top Copper) |
| :---: |
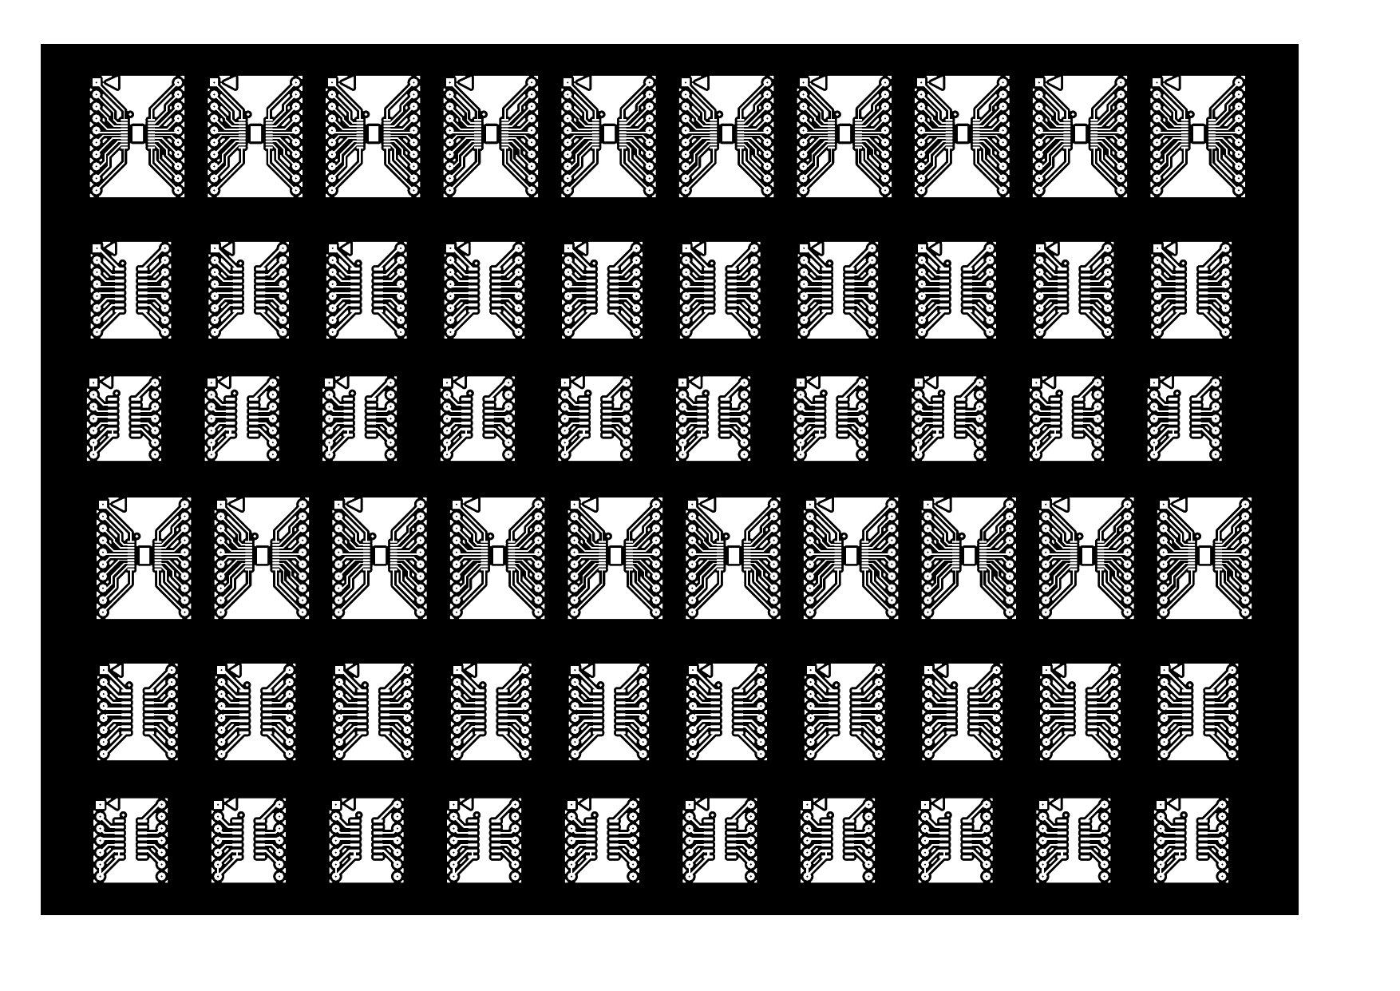
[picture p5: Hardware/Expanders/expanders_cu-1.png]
Expander Board Copper Layout
|  |

---

## Adapter Modules & IC Support

| Module Target | IC Footprint | HomeBus Component | Breakout Pitch | Application & Purpose |
| :--- | :--- | :--- | :--- | :--- |
| **Transceiver Breakout** | SOIC-14 (1.27 mm pitch) | Maxim `MAX491CSD` / `MAX491ESD` | 2.54 mm (0.1") Standard DIP Header | Rapid testing of RS-422 differential transmission lines, termination experiments (120Ω resistors), and oscilloscope waveform verification. |
| **Shift Register Breakout**| SOIC-16 (1.27 mm pitch) | NXP / TI `74HC165D` | 2.54 mm (0.1") Standard DIP Header | Prototyping input daisy-chaining, evaluating switch debounce RC filters, and verifying SPI/serial timing (`PL_`, `CP`, `Q7`). |
| **MCU Breakout** | TSSOP-20 (0.65 mm pitch) | WCH `CH32X033F8P6` | 2.54 mm (0.1") Standard DIP Header | Breadboard development, SWD debugging via WCH-LinkE, and hardware expansion before assembling production in-wall PCBs. |

---

## Hardware Specification & PCB Features

- **Standard Breadboard Compatibility**: Spacing between header rows aligns with standard 300-mil and 600-mil breadboards and female socket strips.
- **Test Points & Silkscreen**: Clearly marked pin numbers and signal designations for probe grounding and logic analyzer clip attachment.
- **Fabrication Plots**:
  - Top Copper Layer: [`Expanders-F_Cu.pdf`](Expanders-F_Cu.pdf)
  - Solder Paste Mask: [`Expanders-F_Paste.pdf`](Expanders-F_Paste.pdf)
  - Board Outline / Dimensioning: [`Expanders-Edge_Cuts.pdf`](Expanders-Edge_Cuts.pdf)

---

## Navigation

- [← Hardware Subsystem Overview](../README.md)
- [↑ HomeBus Root Documentation](../../README.md)
- [Base Node Documentation →](../base_node/README.md)
- [Gateway Node Documentation →](../Gateway_node/README.md)
- [Fan Controller Node Documentation →](../Fan_Controller_node/README.md)
- [Firmware & Protocol Specification →](../../Firmware/README.md)

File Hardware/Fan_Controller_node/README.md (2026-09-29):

# HomeBus Fan Controller Node

The **HomeBus Fan Controller Node** is an intelligent, solid-state AC speed controller designed for residential ceiling fans, exhaust fans, and inductive motor loads. 

Unlike traditional multi-tap capacitor regulators or noisy phase-triac dimmers, the HomeBus Fan Controller combines zero-crossing detection, galvanically isolated gate driving, solid-state MOSFET switching, real-time load current sensing, and temperature monitoring on the RS-422 bus.

---

## Circuit Architecture

```mermaid
flowchart TD
    subgraph MainsPower ["230V AC Mains Interface"]
        LINE_IN["AC Line In (L_in)"] --> FUSE["1A Slow-Blow Fuse\n(2010T1A250V)"]
        FUSE --> MOV["10D471K Varistor\n(Surge Clamping)"]
        MOV --> ZCD["H11AA1 AC Optocoupler\n(Zero-Crossing Detection)"]
        MOV --> CT["ZHT103 / HWCT-5A\n(Current Transformer)"]
        CT --> MOS_STAGE["KIA7N65H Power MOSFET\n(Solid-State AC Switch)"]
        MOS_STAGE --> LINE_OUT["Controlled AC Out (L_out)"]
        NEUTRAL["AC Neutral (N)"] --- ZCD
        NEUTRAL --- MOV
    end

    subgraph IsolationDrive ["Galvanic Gate Drive Isolation"]
        DCDC["Hi-Link B2415S-1WR3\n(Isolated 24V -> 15V DC)"] --> GATE_DRV["HCPL-3120 / VO3120\n(High-CMR Optocoupled Gate Driver)"]
        GATE_DRV -->|15V Isolated Gate Pulse| MOS_STAGE
    end

    subgraph CoreMCU ["Control & Telemetry Subsystem"]
        MCU["WCH CH32X033F8P6\n(32-bit QingKe RISC-V @ 48 MHz)"]
        ZCD -->|ZCD Sync Pulse (EXTI)| MCU
        MCU -->|PWM Gate Trigger| GATE_DRV
        CT -->|Burden Resistor + MCP6001 Op-Amp| MCU
        NTC["10kΩ NTC Thermistor\n(Heatsink Temp)"] --> MCU
        LED["WS2812B RGB Status LED"] <--- MCU
    end

    subgraph BusComm ["HomeBus Network Interface"]
        DIP["8-Bit DIP Switch\n(Hardware Node ID)"] --> SR["74HC165D Shift Register"] --> MCU
        XCVR["MAX491E Transceiver\n(RS-422 Full-Duplex)"] <--> MCU
        TVS["SM712 TVS Array"] <--> XCVR
    end
```

---

## Key Hardware Components

| Subsystem | Component | Package | Technical Details & Function |
| :--- | :--- | :--- | :--- |
| **Microcontroller** | WCH `CH32X033F8P6` | TSSOP-20 | 32-bit QingKe RISC-V core @ 48 MHz. Manages zero-crossing interrupt timing, phase-angle phase delay calculation, anti-stall algorithms, and current telemetry. |
| **Zero-Crossing Detector** | Fairchild/Vishay `H11AA1` | DIP-6 | Bidirectional AC-input optocoupler. Generates clean logic pulses at 100 Hz (50 Hz mains) to sync phase-angle timing with sub-microsecond precision. |
| **Isolated Gate Driver** | Broadcom `HCPL-3120` / `VO3120` | DIP-8 / SOP-8 | High-speed optocoupled MOSFET/IGBT gate driver with 2.5A peak output and high common-mode rejection (CMR > 15 kV/µs). Protects logic from mains transients. |
| **Isolated DC-DC** | Hi-Link `B2415S-1WR3` | SIP-4 | 1W galvanically isolated DC-DC converter (24VDC in to 15VDC out, 67mA). Supplies clean, isolated 15V power to the floating MOSFET gate driver stage. |
| **Power Switching** | KEC `KIA7N65H` | TO-220F | 650V, 7A N-channel Power MOSFET in a fully electrically isolated package. Delivers low $R_{DS(on)}$ ($1.4\ \Omega$), eliminating acoustic motor hum. |
| **Current Sensing** | `ZHT103` / `HWCT-5A` | Through-Hole | 5A rated AC current transformer (5mA secondary ratio). Paired with Microchip `MCP6001` op-amp to report real-time fan power consumption and detect stalled blades. |
| **Over-Temperature** | `10kΩ NTC` Thermistor | 0805 / Radial | Monitors MOSFET junction and enclosure temperature for automated thermal throttling and fire prevention. |
| **Surge Clamping** | `10D471K` Varistor | Radial Disc (10mm) | Metal Oxide Varistor (MOV) clamping mains voltage spikes up to 470V / 2.5 kA. |
| **Overcurrent Fuse** | `2010T1A250V` Micro Fuse | 2010 / Radial | 1A, 250V AC slow-blow time-lag fuse preventing catastrophic damage during hard short circuits. |
| **RS-422 Transceiver** | Maxim `MAX491E` | SOP-14 | Differential full-duplex transceiver protected by `SM712` asymmetrical TVS diodes. |
| **Input Multiplexer** | NXP/TI `74HC165D` | SOP-16 | Parallel-in serial-out shift register sampling the 8-bit DIP switch for hardware node addressing. |

---

## Operating Principles & Control Logic

### 1. Phase-Angle Speed Modulation
- Upon receiving a zero-crossing event from the `H11AA1`, an MCU hardware timer is reset.
- The timer counts down the firing delay $\tau$ corresponding to the desired speed percentage (0–100%).
- At timer expiration, a high-current trigger pulse is sent via the `HCPL-3120` to switch the `KIA7N65H` MOSFET.

### 2. Stall Threshold Protection
Induction ceiling fans exhibit non-linear low-speed torque characteristics. If driven below their aerodynamic stall threshold:
- The motor generates excessive heat without rotating.
- Back-EMF drops to zero, drawing destructive stall currents.
- The Fan Node firmware enforces a **calibrated minimum speed floor** (typically 15–20%). Any command requesting a speed below this threshold is automatically clamped to the minimum floor or switched completely `OFF`.

### 3. Soft Acceleration & Inrush Limiting
When transitioning from stop (`0%`) to a higher speed setting (e.g. `80%`), the firmware applies a smooth acceleration ramp over 1.5–2.5 seconds. This prevents inductive kickback, prolongs bearing life, and eliminates current spikes on the residential electrical circuit.

### 4. Telemetry Reporting
The Fan Controller reports telemetry directly to the central controller (Home Assistant `0xFFFF`):
- **Current & Power (`0x05` / `0x06`)**: Active wattage and RMS current computed from the current transformer.
- **Board Temperature (`0x0A`)**: Heatsink thermal telemetry from the 10kΩ NTC thermistor.
- **RPM / Fan State (`0x09`)**: Derived speed confirmation.

---

## Supported Protocol Commands

In accordance with the [HomeBus Protocol Specification](../../Firmware/README.md):

| Command Code | Command Name | Payload | Behavior |
| :---: | :--- | :--- | :--- |
| `0x01` | `SET_STATE` | `0x00` (OFF) / `0x01` (ON) | Switches fan completely off or returns to last active speed setting. |
| `0x02` | `TOGGLE` | None | Inverts current operating state. |
| `0x03` | `SET_PERCENT` | `0` to `100` (1 byte) | Sets precise speed percentage (clamped to stall threshold). |
| `0x04` | `INCREASE_PERCENT`| Delta `+1%` to `+100%` | Increments current speed by requested step (e.g. `+15%`). |
| `0x05` | `DECREASE_PERCENT`| Delta `-1%` to `-100%` | Decrements current speed by requested step (e.g. `-15%`). |
| `0x09` | `IDENTIFY` | Duration (seconds) | Flashes the onboard WS2812B NeoPixel in rapid pattern for physical locating. |

---

## Navigation

- [← Hardware Subsystem Overview](../README.md)
- [↑ HomeBus Root Documentation](../../README.md)
- [Base Node Documentation →](../base_node/README.md)
- [Gateway Node Documentation →](../Gateway_node/README.md)
- [Expander Daughterboards Documentation →](../Expanders/README.md)
- [Firmware & Protocol Specification →](../../Firmware/README.md)

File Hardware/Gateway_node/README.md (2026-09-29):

# HomeBus Gateway Node

The **HomeBus Gateway Node** serves as the vital routing bridge, segmentation barrier, and protocol proxy between the central HomeBus **Trunk Backbone Bus** and individual **Room Sub-Buses**.

By dividing the physical automation topology into isolated room-level segments, the Gateway prevents local switch bounces, encoder streams, and internal room traffic from congesting the primary backbone while safeguarding against bus-wide failures.

---

## Visual Previews

### Development Board Copper Layout
The development breakout board provides full access to debugging interfaces, bus headers, and test points:

| Gateway Node Dev Board (Top Copper) |
| :---: |
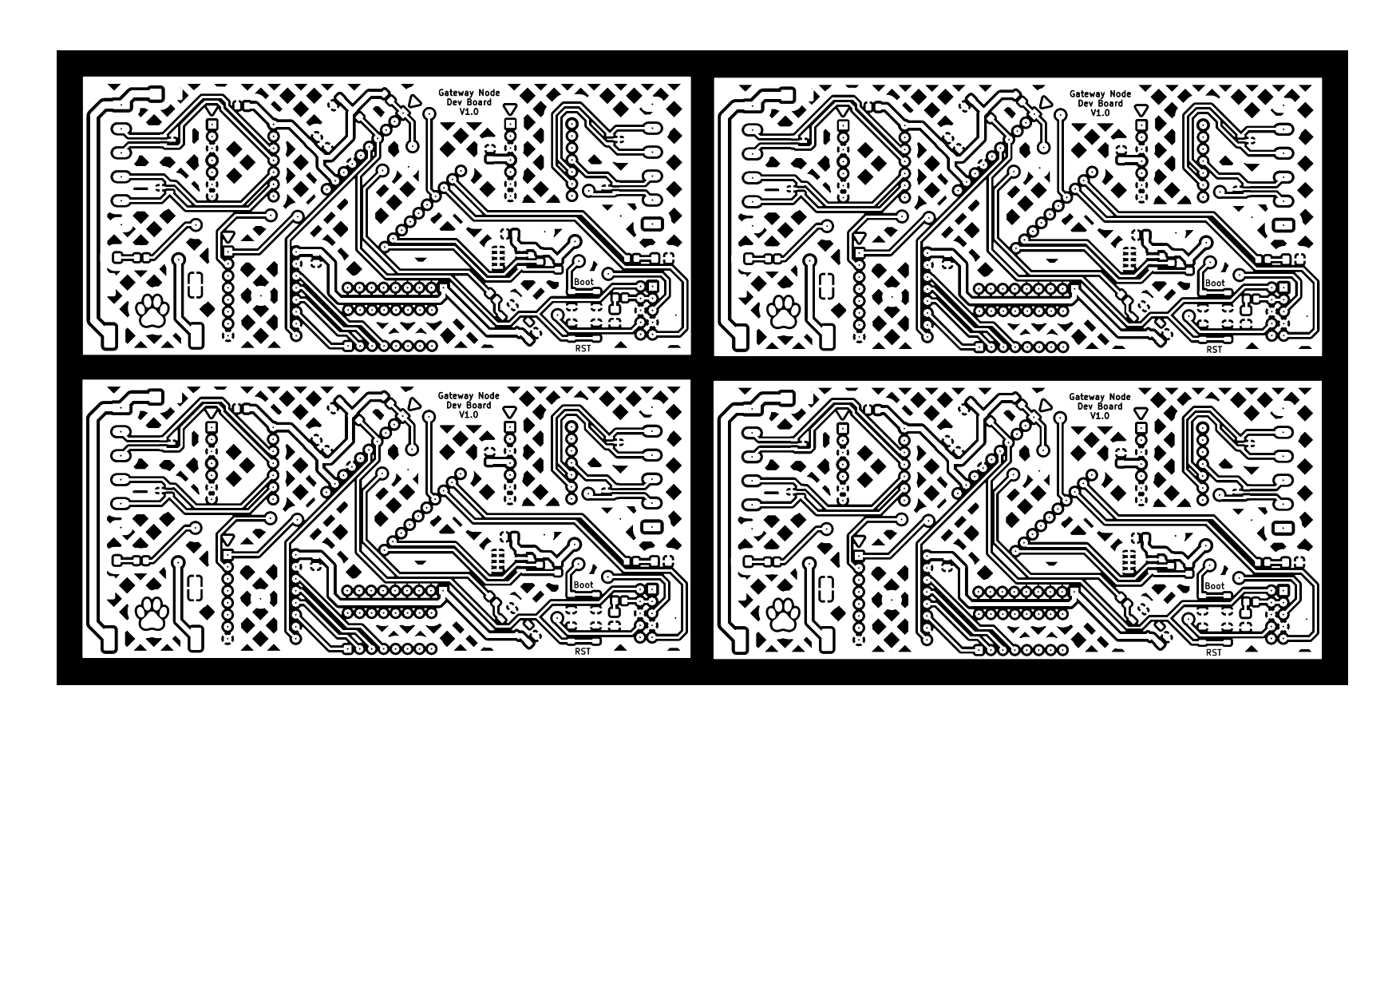
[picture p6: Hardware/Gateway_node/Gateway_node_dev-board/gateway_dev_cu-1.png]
Gateway Dev Board Layout
|  |

---

## System Architecture & Routing Principle

```mermaid
flowchart TD
    subgraph Backbone ["Backbone Trunk (24V + RS-422)"]
        HA["Home Assistant Controller\n(Address: 0xFFFF)"] <--> TRUNK_BUS["Trunk RS-422 Differential Pair"]
    end

    subgraph GatewayNode ["HomeBus Gateway Node"]
        TRUNK_XCVR["Trunk MAX491\nTransceiver"]
        MCU["WCH CH32X033F8P6\n(32-bit QingKe RISC-V)"]
        ROOM_XCVR["Room MAX491\nTransceiver"]
        EEPROM["AT24C256 / CAT24C256\n(256 Kbit I2C EEPROM)"]
        LED_TRUNK["Traffic LED Trunk\n(Activity Monitor)"]
        LED_ROOM["Traffic LED Room\n(Activity Monitor)"]
        DIP["8-Bit DIP Switch\n(Gateway Node ID)"]

        TRUNK_BUS <--> TRUNK_XCVR
        TRUNK_XCVR <-->|UART Trunk TX/RX| MCU
        MCU <-->|UART Room TX/RX| ROOM_XCVR
        MCU <-->|I2C SDA/SCL| EEPROM
        MCU --> LED_TRUNK
        MCU --> LED_ROOM
        DIP -->|74HC165 Shift Reg| MCU
    end

    subgraph RoomBus ["Room Sub-Bus (Isolated RS-422)"]
        ROOM_XCVR <--> ROOM_DEVS["Base Nodes / Fan Nodes / Sensor Nodes"]
    end
```

### Gateway Functional Roles
1. **Packet Filtering & Forwarding**:
   - Packets addressed to devices located within the room are routed locally and never leak to the backbone.
   - External commands from Home Assistant (`0xFFFF`) targeting room devices (`0xRRTTDDDD`) are recognized by the Gateway's Room ID prefix (`RR`) and forwarded inward.
   - Sensor telemetry packets from room nodes are forwarded outbound to Home Assistant.
2. **Device Address Resolution & Caching**:
   - The Gateway maintains a local device table in onboard 256-Kbit EEPROM (`AT24C256`).
   - If a logical device (e.g. `0x02030005`) maps to a third-party Tuya smart device or secondary wireless gateway, the Gateway handles the protocol bridge transparently.
3. **OTA Firmware Proxy**:
   - Buffers and relays firmware update blocks destined for individual room nodes, ensuring reliable transmission over point-to-point RS-422 links.

---

## Key Hardware Components

| Component | Part / Package | Subsystem | Description & Function |
| :--- | :--- | :--- | :--- |
| **MCU** | WCH `CH32X033F8P6` (TSSOP-20) | Core Processing | 48 MHz 32-bit RISC-V QingKe V4C core. Manages dual UARTs, packet routing, CRC verification, and routing table lookup. |
| **Trunk Transceiver** | Maxim `MAX491E` (SOP-14) | Backbone Interface | Full-duplex RS-422 transceiver interfacing the high-speed central backbone network. |
| **Room Transceiver** | Maxim `MAX491E` (SOP-14) | Room Sub-Bus | Dedicated full-duplex RS-422 transceiver driving the isolated room sub-bus. |
| **Non-Volatile Memory**| Microchip `AT24C256C` / `CAT24C256` (SOIC-8) | Routing Storage | 256-Kbit (32 KByte) I2C EEPROM. Stores routing tables, device mapping registers, and offline fallback states. |
| **Surge Protection** | ProTek `SM712` (SOT-23) | Bus Protection | Dual asymmetrical TVS diode arrays (-7V to +12V) on both Trunk and Room differential lines. |
| **Shift Register** | TI/NXP `74HC165D` (SOP-16) | Input Multiplexer | Parallel-to-serial shift register reading the 8-position hardware Node ID DIP switch. |
| **Traffic Indicators**| Discrete SMD LEDs + Current Limiters | Diagnostics | Independent status LEDs indicating real-time packet activity on Trunk and Room buses. |
| **Status LED** | Xinglight `XL-1010RGBC` (`WS2812B`) | System Status | Addressable RGB indicator showing boot state, bus lock, error conditions, and sync status. |

---

## Pin Allocation Table

The Gateway Node uses the 20-pin `CH32X033F8P6` to manage dual transceivers, EEPROM, and traffic indication:

| Pin # | MCU Pin | Production Function | Development Function | Net / Description |
| :---: | :---: | :---: | :---: | :--- |
| **1** | PA0 / PC3 | `DNC` | `Boot Switch` | Do Not Connect in Production; Bootloader Entry Switch in Development |
| **2** | PA1 / PC4 | `Room MAX491 DI` | `Room MAX491 DI` | RS-422 Driver Input (MCU UART TX to Room Sub-Bus) |
| **3** | PA2 / PC2 | `Room MAX491 RO` | `Room MAX491 RO` | RS-422 Receiver Output (Room Sub-Bus RX to MCU) |
| **4** | NRST | `RST` | `RST` | Hardware Reset line (active low, pulled high) |
| **5** | PB0 / PC0 | `HC165 Q7` | `HC165 Q7` | 74HC165 Shift Register Serial Data Out (Node ID data) |
| **6** | PB1 | `Neopixel` | `Neopixel` | Single-wire NRZ serial data stream to WS2812B RGB LED |
| **7** | VSS | `GND` | `GND` | System Ground (0V reference) |
| **8** | PB2 / PC6 | `DNC` | `SWDIO` | Do Not Connect in Production; WCH SWD Debug Data in Development |
| **9** | VDD | `VDD` | `VDD` | Logic Supply Rail (+5V / +3.3V) |
| **10** | PB3 / PC8 | `DNC` | `SWD RX` | Do Not Connect in Production; Debug UART RX in Development |
| **11** | PB6 | `I2C SDA` | `I2C SDA` | I2C Serial Data line to CAT24C256 EEPROM |
| **12** | PB7 | `I2C SCL` | `I2C SCL` | I2C Serial Clock line to CAT24C256 EEPROM |
| **13** | PB4 / PC5 | `Traffic Led Trunk` | `Traffic Led Trunk` | Activity LED driver for Trunk Backbone packet transmission |
| **14** | PB5 | `HC165 PL_` | `HC165 PL_` | 74HC165 Shift Register Parallel Load (active low) |
| **15** | PB8 | `HC165 CP` | `HC165 CP` | 74HC165 Shift Register Clock Pulse |
| **16** | PB10 | `MAX491 DI` | `MAX491 DI` | Trunk RS-422 Driver Input (MCU UART TX to Backbone Bus) |
| **17** | PB11 | `MAX491 RO` | `MAX491 RO` | Trunk RS-422 Receiver Output (Backbone Bus RX to MCU) |
| **18** | PB9 / PC7 | `DNC` | `SWCLK` | Do Not Connect in Production; WCH SWD Clock in Development |
| **19** | PA3 / PC1 | `Traffic Led Room` | `Traffic Led Room` | Activity LED driver for Room Sub-Bus packet transmission |
| **20** | PA4 / PC9 | `DNC` | `SWD TX` | Do Not Connect in Production; Debug UART TX in Development |

---

## Development Board Breakout

The repository includes a dedicated breakout board under [`Gateway_node_dev-board/`](Gateway_node_dev-board/):
- **Features**:
  - Full breakout headers for all 20 MCU pins, allowing logic analyzer probing and rapid breadboard interfacing.
  - Onboard tactile buttons for `Boot` and `Reset`.
  - Dual MAX491 screw terminals and test pin sockets.
  - Dedicated WCH-LinkE programming header (SWDIO, SWCLK, 3.3V, GND, TX, RX).
- **Fabrication Plots**:
  - Top Copper: [`Gateway_node_dev-board-F_Cu.pdf`](Gateway_node_dev-board/Gateway_node_dev-board-F_Cu.pdf)
  - Bottom Copper: [`Gateway_node_dev-board-B_Cu.pdf`](Gateway_node_dev-board/Gateway_node_dev-board-B_Cu.pdf)
  - Outline: [`Gateway_node_dev-board-Edge_Cuts.pdf`](Gateway_node_dev-board/Gateway_node_dev-board-Edge_Cuts.pdf)

---

## Navigation

- [← Hardware Subsystem Overview](../README.md)
- [↑ HomeBus Root Documentation](../../README.md)
- [Base Node Documentation →](../base_node/README.md)
- [Fan Controller Node Documentation →](../Fan_Controller_node/README.md)
- [Expander Daughterboards Documentation →](../Expanders/README.md)
- [Firmware & Protocol Specification →](../../Firmware/README.md)

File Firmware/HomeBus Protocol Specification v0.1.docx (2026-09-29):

# HomeBus Protocol Specification v0.1

## Overview

HomeBus is a distributed home automation network using:

- Full-duplex RS422
- 24V power distribution
- CH32X033-based nodes
- Gateway-based room segmentation
- Home Assistant as the system controller

The protocol is designed around:

- Physical Node IDs
- Logical Device Addresses
- OTA firmware deployment
- Distributed control
- Gateway routing
- Home Assistant integration

# Terminology

## Node

A physical HomeBus device.

Examples:

- Relay Node
- Fan Node
- Sensor Node
- Gateway Node
- Input Node

Each node has a unique:

Node ID

assigned using the 8-position DIP switch.

Node IDs are used for:

- Commissioning
- OTA updates
- Diagnostics
- Telemetry

Node IDs are NOT used for normal device control.

## Device

A logical controllable endpoint.

Examples:

- Bedroom Light
- Fan
- RGB Controller
- Spot Light
- Tuya Light

Each device has a logical:

Device Address

which is independent of the physical node.

This allows devices to be migrated between:

- HomeBus hardware
- Tuya devices
- Future integrations

without reconfiguring input nodes.

# Address Format

Device addresses are 32-bit.

0xRRTTDDDD

Where:

RR = Room ID (8-bit)
TT = Device Type (8-bit)
DDDD = Device ID (16-bit)

Example:

0x02030005

Meaning:

Room 02
Type 03 (Spotlight)
Device 0005

# Reserved Addresses

0xFFFF

Home Assistant Controller

All telemetry is sent to this address.

# Node IDs

Node IDs are separate from Device Addresses.

Example:

Node ID = 42

This node may expose:

0x02030001
0x02030002
0x02030003
0x02030004

Each representing a separate relay output.

# Packet Types

HomeBus uses two primary packet classes.

## Control Packet

Used to control a logical device.

Structure:

Destination Address
Command
Payload Length
Payload
CRC16

Example:

Destination:
0x02030005

Command:
SET_STATE

Payload:
ON

The destination device executes the command.

The source is not transmitted.

The destination does not care who initiated the command.

## Telemetry Packet

Used by sensors and status-reporting nodes.

Structure:

Destination Address
Node ID
Sensor Type
Payload Length
Payload
CRC16

Example:

Destination:
0xFFFF

Node ID:
73

Sensor:
TEMPERATURE

Value:
26.4

Home Assistant resolves:

Node 73
+
Temperature

to the configured room and entity.

# Sensor Types

Suggested values:

0x01 Temperature
0x02 Humidity
0x03 Presence
0x04 Light Level
0x05 Current
0x06 Power
0x07 Voltage
0x08 Energy
0x09 Fan RPM
0x0A NTC Temperature

Additional types may be added later.

# Control Commands

Suggested values:

0x01 SET_STATE
0x02 TOGGLE
0x03 SET_PERCENT
0x04 INCREASE_PERCENT
0x05 DECREASE_PERCENT
0x06 SET_BRIGHTNESS
0x07 SET_COLOR
0x08 SET_PATTERN
0x09 IDENTIFY

# Gateway Operation

Gateways connect:

Backbone Bus

to

Room Bus

using two MAX491 transceivers.

Gateways maintain:

- Node table
- Device table
- Local cache
- Tuya mapping table

Gateways do NOT own device logic.

Gateways act as:

- Packet routers
- Protocol bridges
- OTA forwarders

# Device Resolution

Example:

0x02030005

may map to:

Tuya Device

today.

Later it may map to:

HomeBus Relay

without changing any switch configuration.

Input nodes only know:

Destination Address

and never know the implementation behind it.

# Sensor Reporting Policy

## Event Driven

Used for:

Presence
Door Sensors
Window Sensors
Switch Inputs
Encoders

Packets are transmitted only when state changes.

## Periodic

Used for:

Temperature
Humidity
Light Level
Power Monitoring

Packets are transmitted at configurable intervals.

Recommended:

30s - 300s

depending on sensor type.

# Fan Control

Fan nodes use fixed hardware mappings.

No pin-discovery commissioning is required.

Supported commands:

SET_PERCENT
INCREASE_PERCENT
DECREASE_PERCENT

Example:

+15%

The fan node maintains its own:

- Current speed
- Minimum stable speed
- Calibration data

The fan node is responsible for ensuring operation remains above stall threshold.

# Commissioning

Blank nodes boot into commissioning mode.

Node transmits:

Commission Request
Node ID
Capabilities

to Home Assistant.

If the Node ID already exists:

Firmware is restored automatically.

If the Node ID is unknown:

New commissioning process begins.

# OTA Updates

All nodes contain a permanent bootloader.

Recommended flash layout:

Bootloader

Slot A
Slot B

Update process:

Download new image
Verify CRC
Switch active slot
Reboot
Confirm health

Rollback occurs automatically if the new image fails.

# Reliability

All packets include:

CRC16

Invalid packets are discarded.

HomeBus uses:

Full Duplex RS422

throughout the network.

This allows:

- OTA updates
- Telemetry
- Control packets

to coexist without bus arbitration.

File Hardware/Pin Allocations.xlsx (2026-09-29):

CH32X033 |  |  |  | CH32X033 |  |  | CH32X033
Standard Pin Allocations |  |  |  | Base Node Pin Allocations |  |  | Gateway Node Pin Allocations
Pin | Function | Production | Development |  | Function |  |  | Function
1 | Boot Switch | r | a | Pin | Production | Development | Pin | Production | Development
2 | Room MAX491 DI | a | a | 1 | GPIOC 3 | Boot Switch | 1 | DNC | Boot Switch
3 | Room MAX491 RO | a | a | 2 | GPIOC 4 | GPIOC 4 | 2 | Room MAX491 DI | Room MAX491 DI
4 | RST | a | a | 3 | GPIOC 2 | GPIOC 2 | 3 | Room MAX491 RO | Room MAX491 RO
5 | HC165 Q7 | a | a | 4 | RST | RST | 4 | RST | RST
6 | Neopixel | a | a | 5 | HC165 Q7 | HC165 Q7 | 5 | HC165 Q7 | HC165 Q7
8 | SWDIO | r | a | 6 | Neopixel | Neopixel | 6 | Neopixel | Neopixel
10 | SWD RX | r | a | 7 | GND | GND | 7 | GND | GND
14 | HC165 PL_ | a | a | 8 | GPIOC 6 | SWDIO | 8 | DNC | SWDIO
15 | HC165 CP | a | a | 9 | VDD | VDD | 9 | VDD | VDD
16 | MAX491 DI | a | a | 10 | GPIOC 8 | SWD RX | 10 | DNC | SWD RX
17 | MAX491 RO | a | a | 11 | I2C SDA | I2C SDA | 11 | I2C SDA | I2C SDA
18 | SWCLK | r | a | 12 | I2C SCL | I2C SCL | 12 | I2C SCL | I2C SCL
20 | SWD TX | r | a | 13 | GPIOC 5 | GPIOC 5 | 13 | Traffic Led Trunk | Traffic Led Trunk
 |  |  |  | 14 | HC165 PL_ | HC165 PL_ | 14 | HC165 PL_ | HC165 PL_
 |  |  |  | 15 | HC165 CP | HC165 CP | 15 | HC165 CP | HC165 CP
 |  |  |  | 16 | MAX491 DI | MAX491 DI | 16 | MAX491 DI | MAX491 DI
 |  |  |  | 17 | MAX491 RO | MAX491 RO | 17 | MAX491 RO | MAX491 RO
 |  |  |  | 18 | GPIOC 7 | SWCLK | 18 | DNC | SWCLK
 |  |  |  | 19 | GPIOC 1 | GPIOC 1 | 19 | Traffic Led Room | Traffic Led Room
 |  |  |  | 20 | GPIOC 9 | SWD TX | 20 | DNC | SWD TX

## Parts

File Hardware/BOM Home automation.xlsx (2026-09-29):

Component Name | Listing | Price | Product Description | Quantity | Initial Quantity | URL | Alternate URL | Total | Initial Total
CH32X033F8P6 | CH32X033F8P6 TSSOP-20 WCH RISC-V Microcontrollers A2047 | 36 | MCU | 41 | 6 | https://www.etstore.in/products/a2047?variant=46807856611579&country=IN&currency=INR |  | 1476 | 216
MAX491 | MAX491 MAX491CSD MAX491ESD SOP-14 Transceiver IC | 26 | RS422 Transciver | 49 | 7 | https://inkocean.in/products/max491-max491csd-max491esd-sop-14-transceiver-ic?variant=20106335191158 |  | 1274 | 182
WS2812B-1010 NeoPixel | WS2812B SMD1010 Addressable RGB LED – Neopixel LED | 4 | Indicator LED | 41 | 6 | https://quartzcomponents.com/products/ws2812b-smd1010-addressable-rgb-led-neopixel-led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 |  | 164 | 24
8 Pin DIP Switch | 8 Way DIP Switch 2.54mm Pitch Slide ET8011 | 13 | DIP Switch 8 channel | 41 | 6 | https://www.etstore.in/products/b8011?_pos=1&_sid=518f04376&_ss=r | https://roboticsdna.in/product/8-way-dip-switch/ | 533 | 78
74HC165D | 74HC165 74HC165D SOP-16 high Speed CMOS logic devices | 12 | Shift Register PISO | 41 | 6 | https://inkocean.in/products/74hc165-74hc165d-sop-16-high-speed-cmos-logic-devices-shift-register |  | 492 | 72
MP1548 | DC-DC MP1584EN 3A Step Down Power Supply Module | 42 | Buck Converter 24-5vdc | 41 | 6 | https://robokits.co.in/power-supply/dc-dc-power-supply/mini-mp1584-dc-dc-step-down-4.5-to-28v-3a-adjustable-buck-module | https://ifuturetech.org/product/dc-dc-mp1584en-3a-step-down-power-supply-module/ | 1722 | 252
SM712 | PSM712-ES Bidirectional TVS diode SOT23 17A 712 7V 12V SM712 350W ET7127 | 3 | TVS | 49 | 7 | https://www.etstore.in/products/g7127?_pos=1&_sid=1c3b00ca3&_ss=r |  | 147 | 21
H11AA1 | H11AA1 Transistor Output Optocoupler IC DIP-6 Package | 40 | Optocoupler | 7 | 1 | https://www.electropi.in/h11aa1-transistor-output-optocoupler-ic |  | 280 | 40
HCPL3120 | HCPL3120 HCPL-3120 A3120 SOP optocouplers | 38 | MOSFET Optocoupler | 7 | 1 | https://inkocean.in/products/hcpl3120-hcpl-3120-a3120-sop-optocouplers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 |  | 266 | 38
B2415S-1W | Hi-Link B2415S-1WR3 – 24VDC to 15VDC 67mA DC To DC Converter Power Module – SIP-4 Package | 260 | DC-DC Isolator 24v-15v | 7 | 1 | https://sharvielectronics.com/product/hi-link-b2415s-1wr3-24vdc-to-15vdc-67ma-dc-to-dc-converter-power-module-sip-4-package/ |  | 1820 | 260
KIA7N65H | KIA7N65H 650V 7A N-Channel Mosfet – TO-220F Package | 47 | AC Switching MOSFET | 14 | 2 | https://sharvielectronics.com/product/kia7n65h-650v-7a-n-channel-mosfet-to-220f-package/ |  | 658 | 94
EC11 Rotary Encoder | Rotary Encoder EC11 20mm Knurled Handle 20 Positions | 49 | Rotary Encoder with push button | 13 | 3 | https://ifuturetech.org/product/ec11-potentiometer-encoder-switch/ |  | 637 | 147
Knob Metal | GOLD ALUMINIUM ALLOY POTENTIOMETER KNOB CAP | 15 | Metal knob for Rotary Encoder | 13 | 3 | https://ifuturetech.org/product/gold-aluminium-alloy-potentiometer-knob-cap/ |  | 195 | 45
INA226 | NA226 IIC Interface Bidirectional Current Power Monitoring Sensor | 107 | Current sensor based on shunt resisor | 1 | 0 | https://www.flyrobo.in/na226-iic-interface-bidirectional-current-power-monitoring-sensor?tracking=ads | https://www.xcluma.com/ina226-bi-directional-current-and-power-monitor-module-high-side-or-low-side-measurement-with-iic-compatible-0v-to-36v | 107 | 0
100A / 75mV Shunt Resistor | XIQI Electric CG FL-2B 100A 75mV DC Current Shunt Resister | 307 | Shunt Resistor | 1 | 0 | https://robu.in/product/cg-fl-2b-100a-75mv/ |  | 307 | 0
BME680 | BME680 Digital Humidity Temperature Pressure High Altitude Sensor Module | 793 | 4 in 1 weather sensor: Baramoter, Temperature, Humidity, VOC | 1 | 0 | https://robocraze.com/products/bme680-temperature-sensor-module?variant=40193794211993&country=IN&currency=INR |  | 793 | 0
BH1750 | GY-302 BH1750 Light Intensity Module | 84 | LUX Meter | 1 | 0 | https://www.theengineerstore.in/products/gy-302-bh1750-light-intensity-module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 |  | 84 | 0
HLK-LD2420 | HLK-LD2420 24GHz Human Micro Motion Radar Module | 262 | 24GHz Presence Sensor | 5 | 1 | https://quartzcomponents.com/products/hlk-ld2420-24ghz-human-micro-motion-radar-module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 |  | 1310 | 262
HLK-LD2402 | Hi-Link HLK-LD2402G-W, 24GHz, Millimeter-Wave Motion Sensor,3.3V/5V, 50 mA, ±60° Coverage, Detection Range: 10m | 165 | 24GHz Presence Sensor | 6 | 1 | https://robu.in/product/hi-link-hlk-ld2402g-w-24ghz-millimeter-wave/ |  | 990 | 165
4 Channel Relay Module with Optocoupler 5v | 5v 4 Channel Relay Module | 146 | 5v 4ch relay module with optocoupler | 5 | 1 | https://www.flyrobo.in/5v_four_channel_relay_module?tracking=ads |  | 730 | 146
GL5528 | GL5528 5mm LDR Sensor Photoresistor Photo Cell 10-20K | 5 | LDR 5mm | 5 | 1 | https://ifuturetech.org/product/gl5528-5mm-ldr-sensor-photoresistor-photo-cell-10-20k/ |  | 25 | 5
8 Channel Relay Module with Optocoupler 5v | 5V 8-Channel Optocoupler Relay Board Module | 229 | 5v 8ch relay module with optocoupler | 1 | 0 | https://techtonics.in/product/5v-8-channel-optocoupler-relay-board-module/ |  | 229 | 0
2 Channel Relay Module with Optocoupler 5v | 5V Dual Channel Relay Module with Optocoupler Isolation | 65 | 5v 2ch relay module with optocoupler | 1 | 0 | https://techtonics.in/product/5v-10a-dual-channel-opto-coupler-relay-module/ |  | 65 | 0
1 Channel Relay Module with Optocoupler 5v | ADIY 1 Channel 5V Relay Module with Optocoupler for Arduino | 52 | 5v 1ch relay module with optocoupler | 7 | 1 | https://robocraze.com/products/adiy-1-channel-5v-relay-module-with-optocoupler-isolation-for-arduino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 |  | 364 | 52
Rain sensor | Rain Sensitive Sensor Module Drop Detection Sensor ET5199 | 42 | Resistive Rain sensor | 1 | 0 | https://www.etstore.in/products/c5199?_pos=1&_sid=f26be2f94&_ss=r | https://quartzcomponents.com/products/rain-drop-sensor-module?variant=31897781534855&country=IN&currency=INR | 42 | 0
INA180A2IDBVR | INA180A2IDBVR SOT-23-5 TI Current Sense Amplifiers TI A2052 | 19 | Current Sense Amplifier | 1 | 1 | https://www.etstore.in/products/a2052?variant=46808199954683&country=IN&currency=INR |  | 19 | 19
24V 5A SMPS | 24V 5A SMPS Power Supply | 730 | 24v 5a Power Supply | 1 | 0 | https://www.theengineerstore.in/products/24v-5a-smps-power-supply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 | https://www.amazon.in/Electronic-Spices-24V-5A-SMPS/dp/B09H4NZ747 | 730 | 0
RSIC-V Programmer | WCH-LinkE-R0-1v3.FP | 572.3 | Programmer required to program the CH32X033 | 1 | 1 | https://www.makestore.in/product/ch32v003-wch-linke-debugger-programmer/ | https://punoscho.in/product/linke-wch-linke-r0-1v3-programming-module-stick/ | 572.3 | 572.3
100nF 0603 | 100NF 50V 0603 SMD Ceramic Capacitor 104 10% walsin X7R ET9251 | 0.2 | Decoupling Capacitor | 100 | 100 | https://www.etstore.in/products/e9251?variant=46786360672507&country=IN&currency=INR |  | 20 | 20
10uF X5R/X7R | 10uF 6.3V SAMSUNG CL10A106MQ8NNNC X5R 10% 0603 MLCC SMD SMT ET7920 | 0.8 | Bulk Capacitance | 100 | 100 | https://www.etstore.in/products/g7920?_pos=4&_sid=9dae4c250&_ss=r |  | 80 | 80
10k Resistor Network | A09-103JP 10K OHM 9 PIN Network Resistor 1/8W 5% ET10164 | 6.37 | Pull-up Resistor Network | 82 | 10 | https://www.etstore.in/search?q=10k+Resistor+Network&options%5Bprefix%5D=last |  | 522.34 | 63.7
330Ω Resistor | 330 OHM 0603 SMD RESISTOR 330R 331 1/16W 5% ET9286 | 0.15 | Current limiting resistor for LED | 100 | 100 | https://www.etstore.in/products/e9747?_pos=8&_sid=6137a4221&_ss=r |  | 15 | 15
100kΩ 1W Resistor | 100K OHM 1W RESISTOR CFR 5% ET10437 | 1.6 |  | 10 | 10 | https://www.etstore.in/products/d10437?_pos=10&_sid=51f39a116&_ss=r |  | 16 | 16
AHT21B | AHT21 High Precision I2C Digital Temperature and Humidity Sensor Module | 99 | Temperature and Humidity Sensor | 12 | 1 | https://ifuturetech.org/product/aht21-high-precision-i2c-digital-temperature-and-humidity-sensor-module/ |  | 1188 | 99
240vac Toggle Switch | 3 Pin Toggle Switch (3A 230V) | 14 | Toggle Switch for smart light hard switching | 35 | 8 | https://www.theengineerstore.in/products/3-pin-toggle-switch-3a-230v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 |  | 490 | 112
CH340C USB C to TTL | CH340C USB to TTL Module TYPE-C | 99 | USB to TTL Converter | 1 | 1 | https://ifuturetech.org/product/ch340c-usb-to-ttl-module-type-c/ |  | 99 | 99
TSSOP-20 Holder | Programming Socket for SSOP20 TSSOP20 to 20pin Breakout with 5.3-5.7mm IC Width and 0.65mm Pitch | 726 | MCU holder for programming | 1 | 1 | https://robokits.co.in/programmers/programming-test-sockets/test-socket-ssop-tssop/programming-socket-for-ssop20-tssop20-to-20pin-breakout-with-5.3-5.7mm-ic-w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 |  | 726 | 726
XY2500 connector pair 6 pin | Xinya XY2500 6 Pin Female Pluggable Terminal - Right Angle & Xinya XY2500 6 Pin Close Type Male Terminal - Pluggable Terminal - Right Angle | 30 | For connecting RS422 Network with 24v | 50 | 7 | https://www.ktron.in/product/xinya-xy2500-6-pin-female-pluggable-terminal/ | https://www.ktron.in/product/xinya-xy2500-6-pin-close-type-male-terminal/ | 1500 | 210
20 pin IDC Male Connector | 20 Pin FRC IDC Box Header Right Angle Male 10x2 Pin 2.54mm | 6 | Modular connection connector |  |  | https://rajivelectronics.com/product/20-pin-frc-idc-box-header-right-angle-male-10x2-pin-2-54mm |  | 0 | 0
20 pin IDC Socket | 20 Pin FRC/IDC Female Connector 10x2 Pin 2.54mm (Ribbon Cable IDC Connector) | 5 | Modular connection connector |  |  | https://rajivelectronics.com/product/20-pin-frc-idc-female-connector-10x2-pin-2-54mm-ribbon-cable-idc-connector |  | 0 | 0
10D471K | 10D 471K Metal Voltage Dependent Resistor | 8 | MOV | 7 | 1 | https://ifuturetech.org/product/10d-471k-metal-voltage-dependent-resistor/ |  | 56 | 8
2010T1A250V | 1A 250V AC rectangular 2010T1A250V Fuse Slow Blow Micro Time Lag type ET8714 | 7 | Fuse | 7 | 1 | https://www.etstore.in/products/b8714?_pos=1&_sid=2fa753249&_ss=r
CAT5e Cable |  | 18 |  | 100 | 0 |  |  | 1800 | 0
PCB Manufacturing |  | 1500 |  | 2 | 0 |  |  | 3000 | 0
 |  |  |  |  |  |  | Total | 25544 | 4139

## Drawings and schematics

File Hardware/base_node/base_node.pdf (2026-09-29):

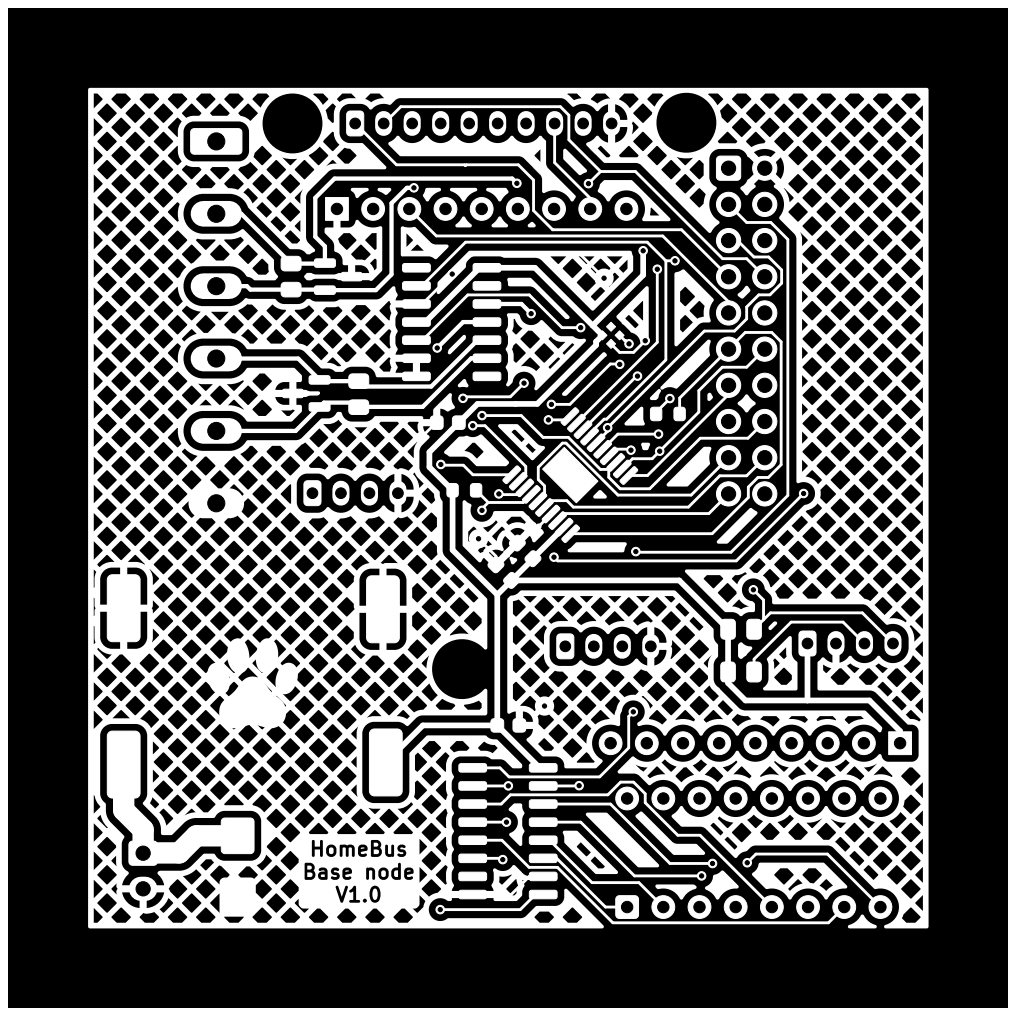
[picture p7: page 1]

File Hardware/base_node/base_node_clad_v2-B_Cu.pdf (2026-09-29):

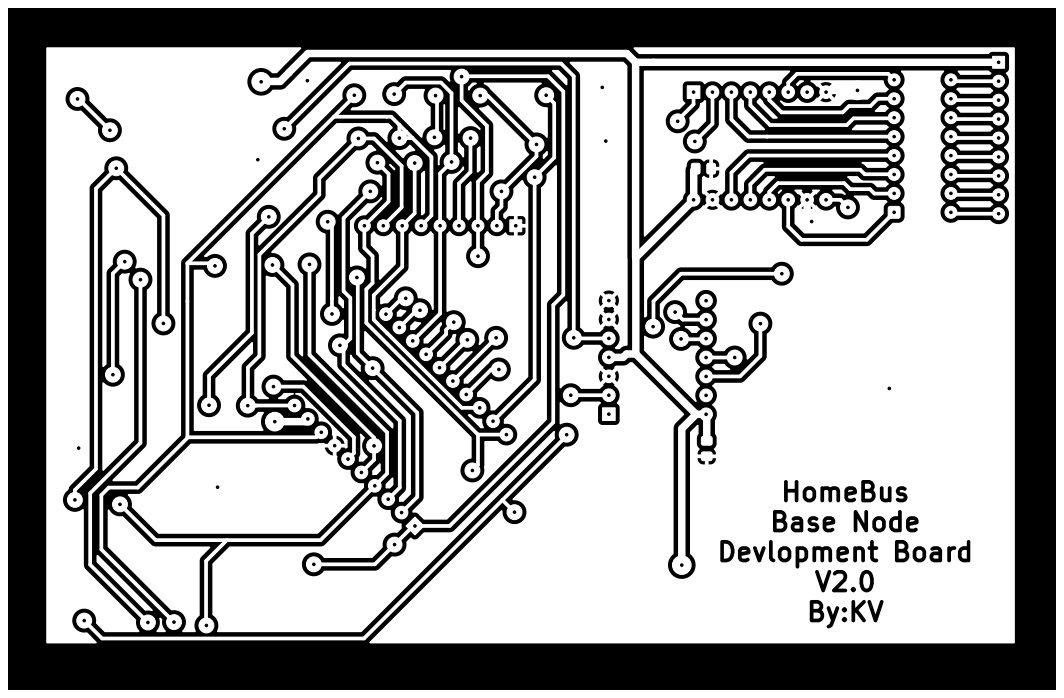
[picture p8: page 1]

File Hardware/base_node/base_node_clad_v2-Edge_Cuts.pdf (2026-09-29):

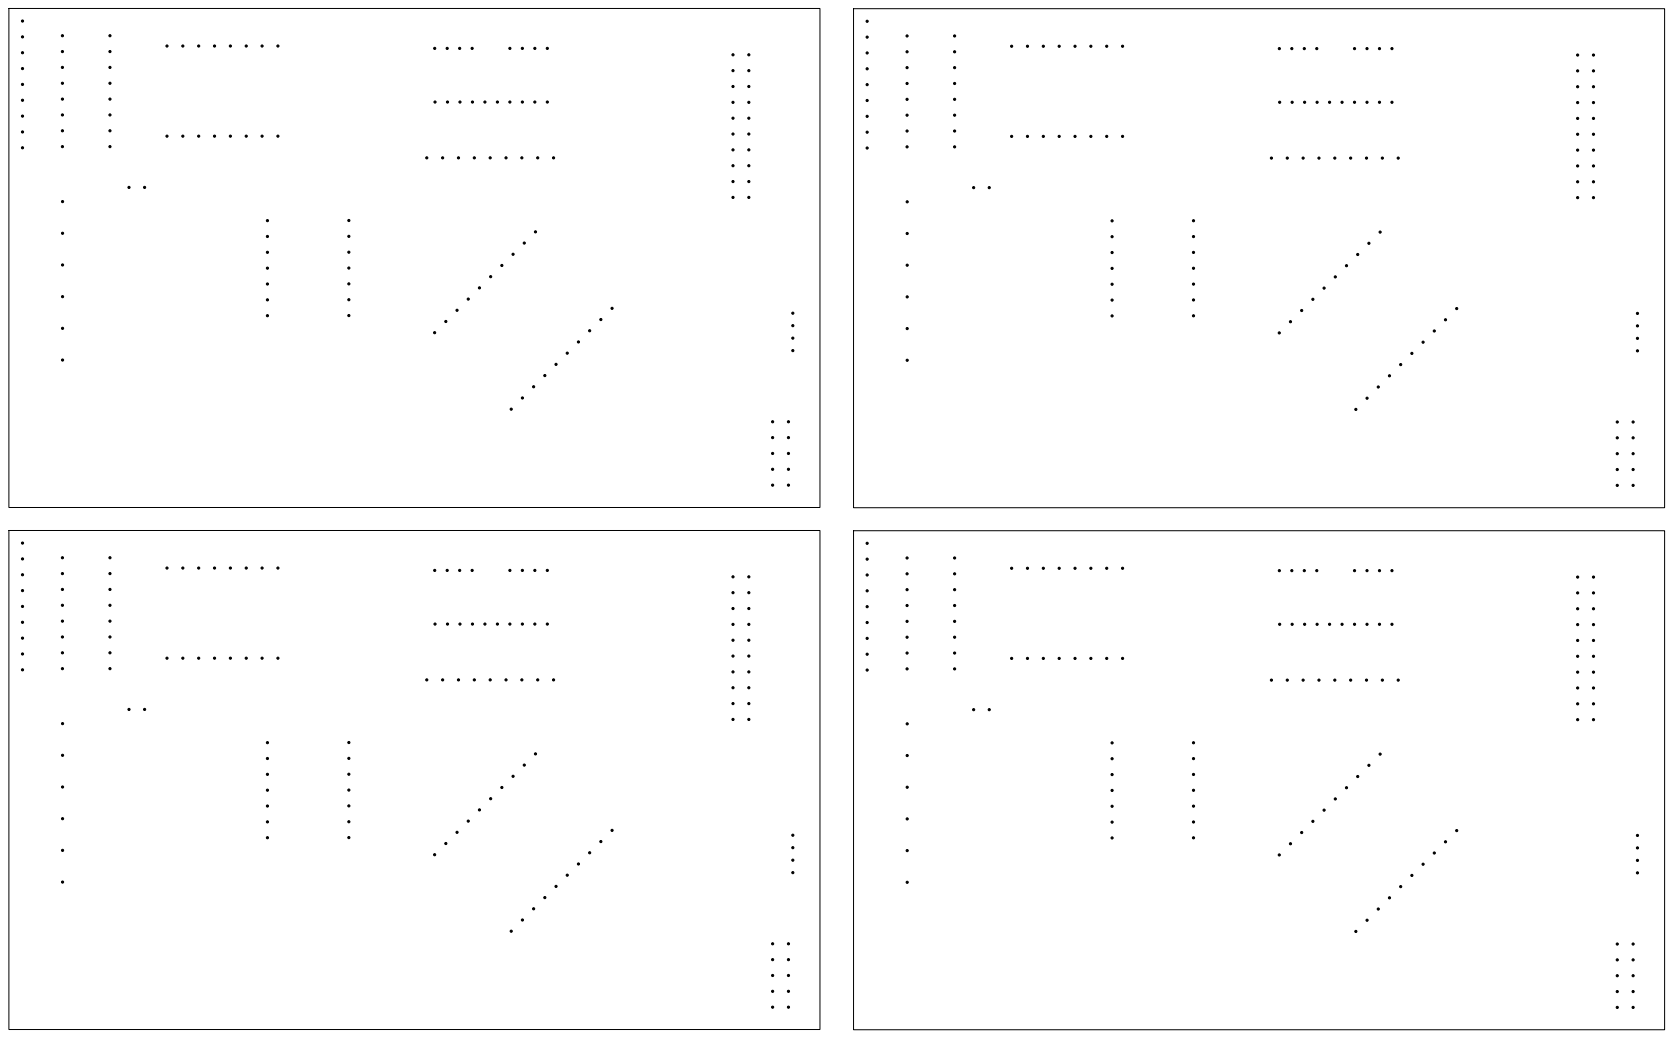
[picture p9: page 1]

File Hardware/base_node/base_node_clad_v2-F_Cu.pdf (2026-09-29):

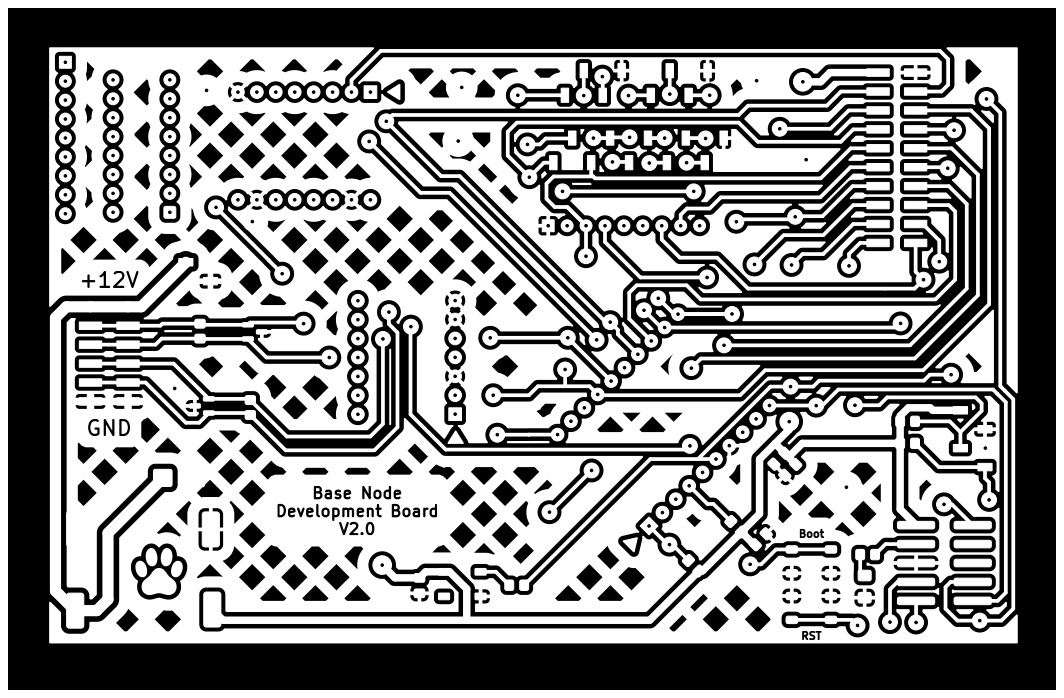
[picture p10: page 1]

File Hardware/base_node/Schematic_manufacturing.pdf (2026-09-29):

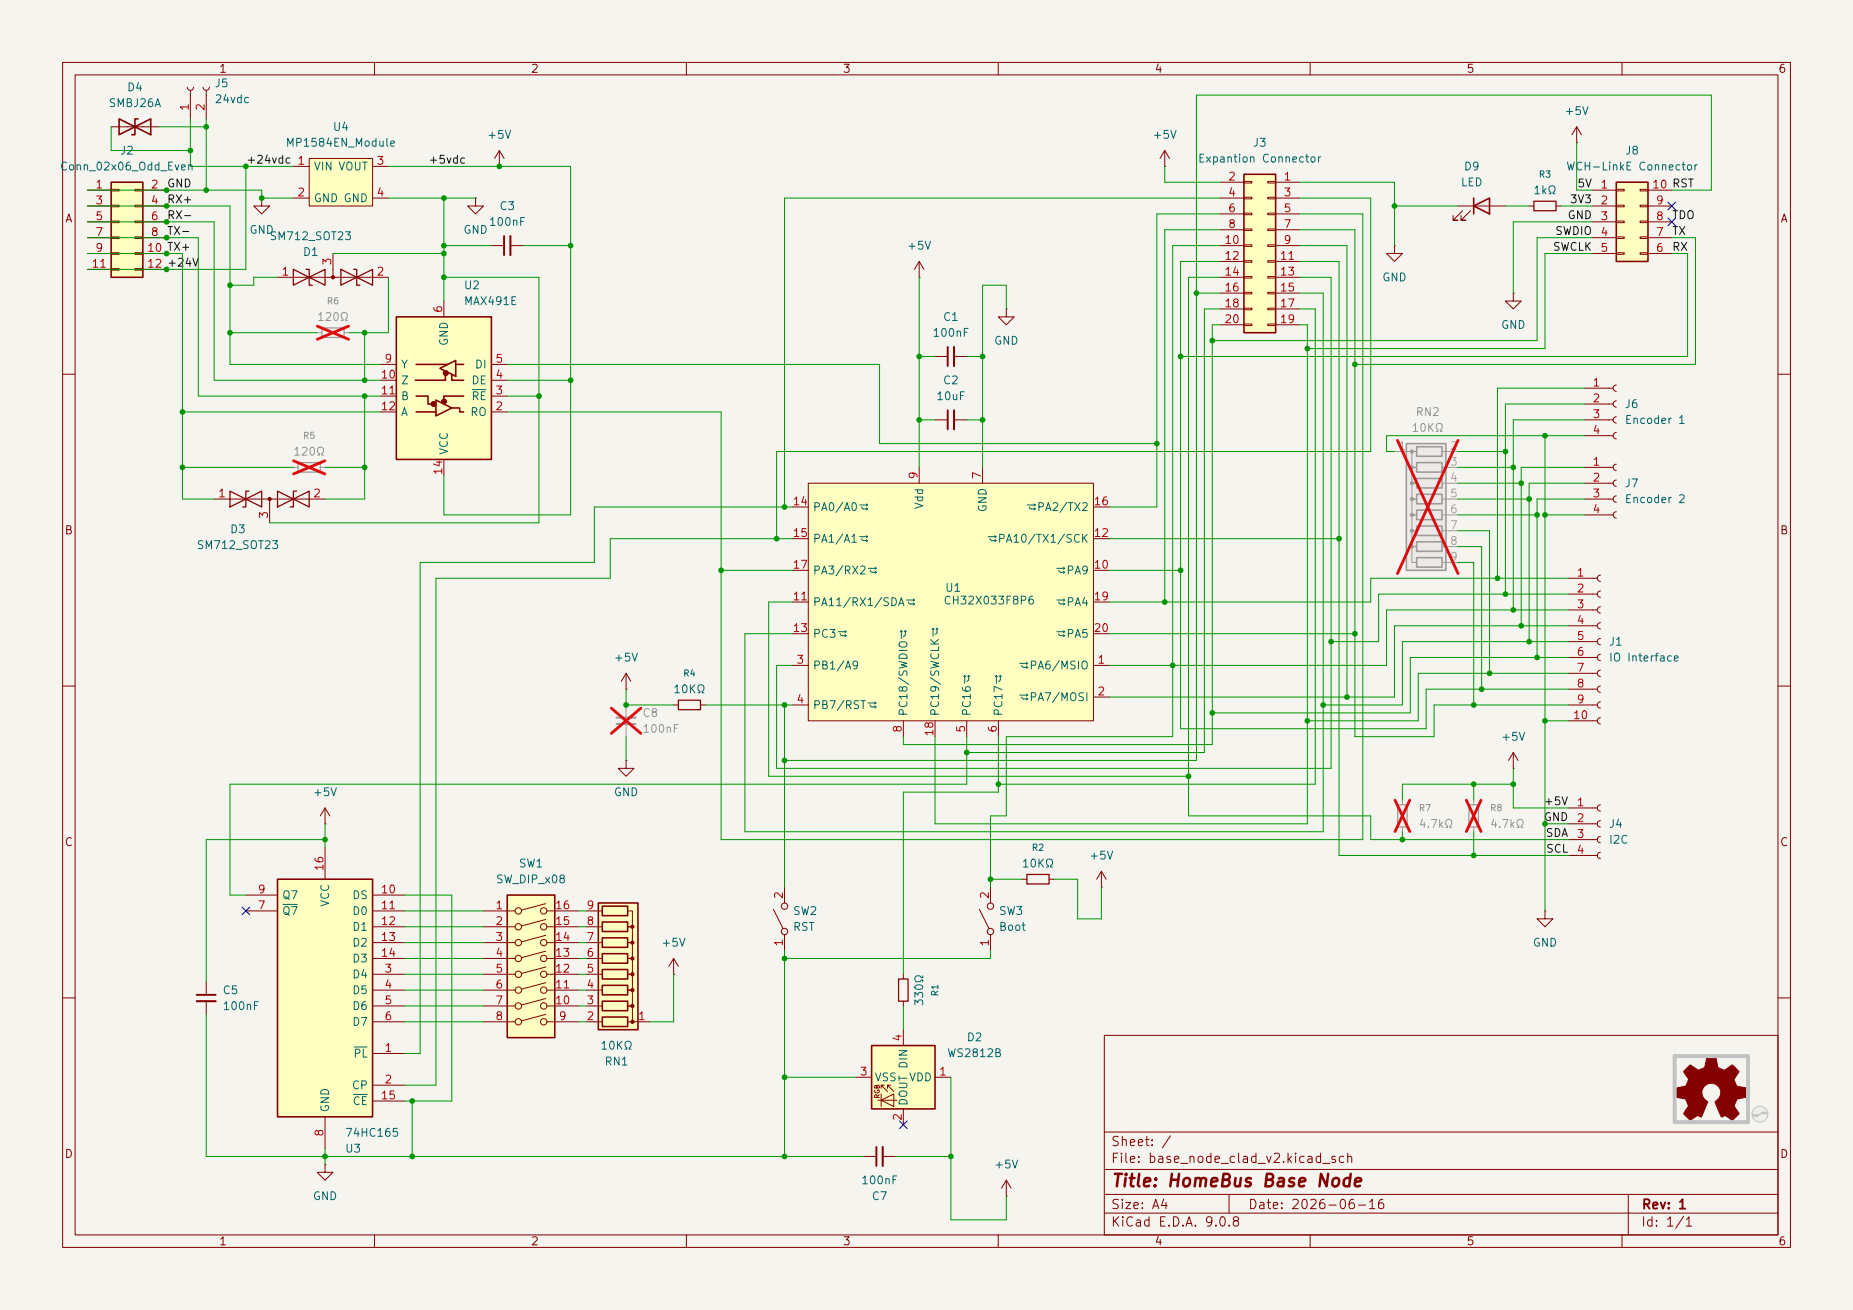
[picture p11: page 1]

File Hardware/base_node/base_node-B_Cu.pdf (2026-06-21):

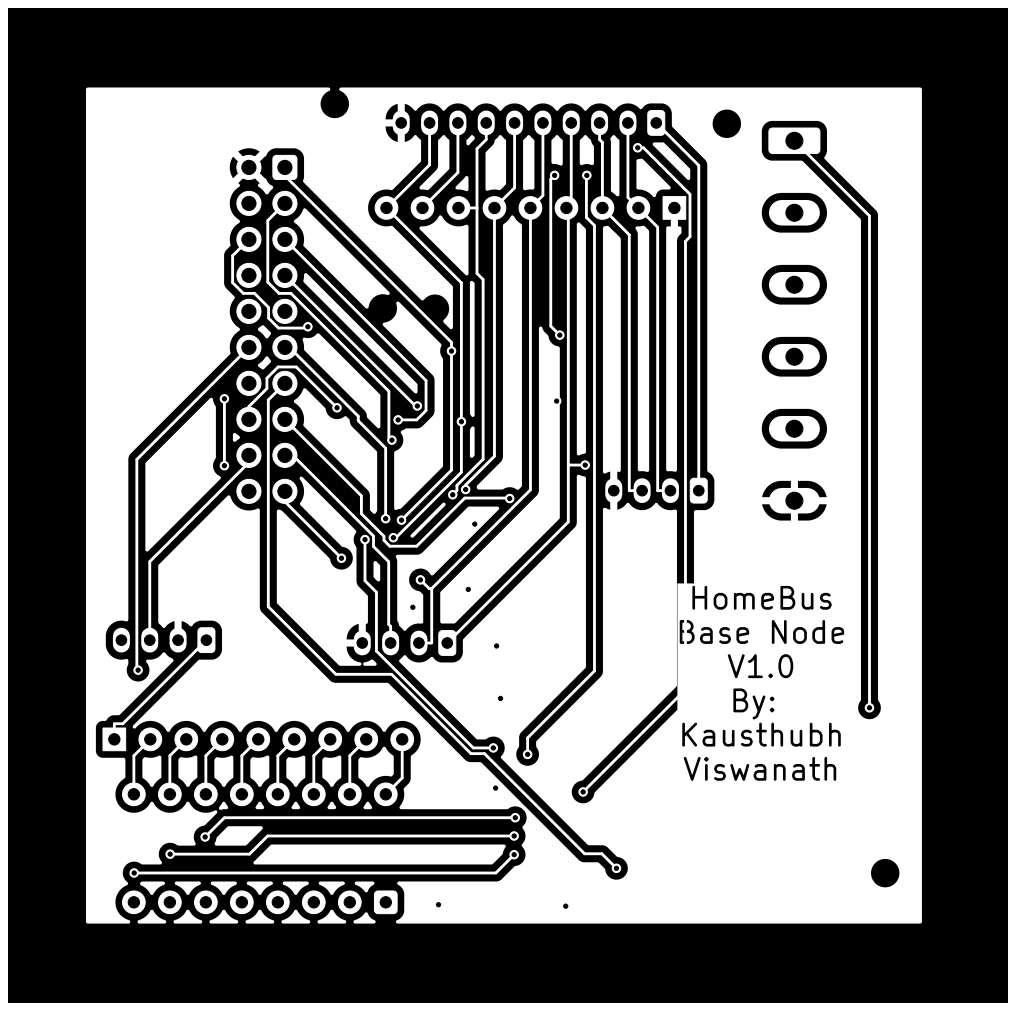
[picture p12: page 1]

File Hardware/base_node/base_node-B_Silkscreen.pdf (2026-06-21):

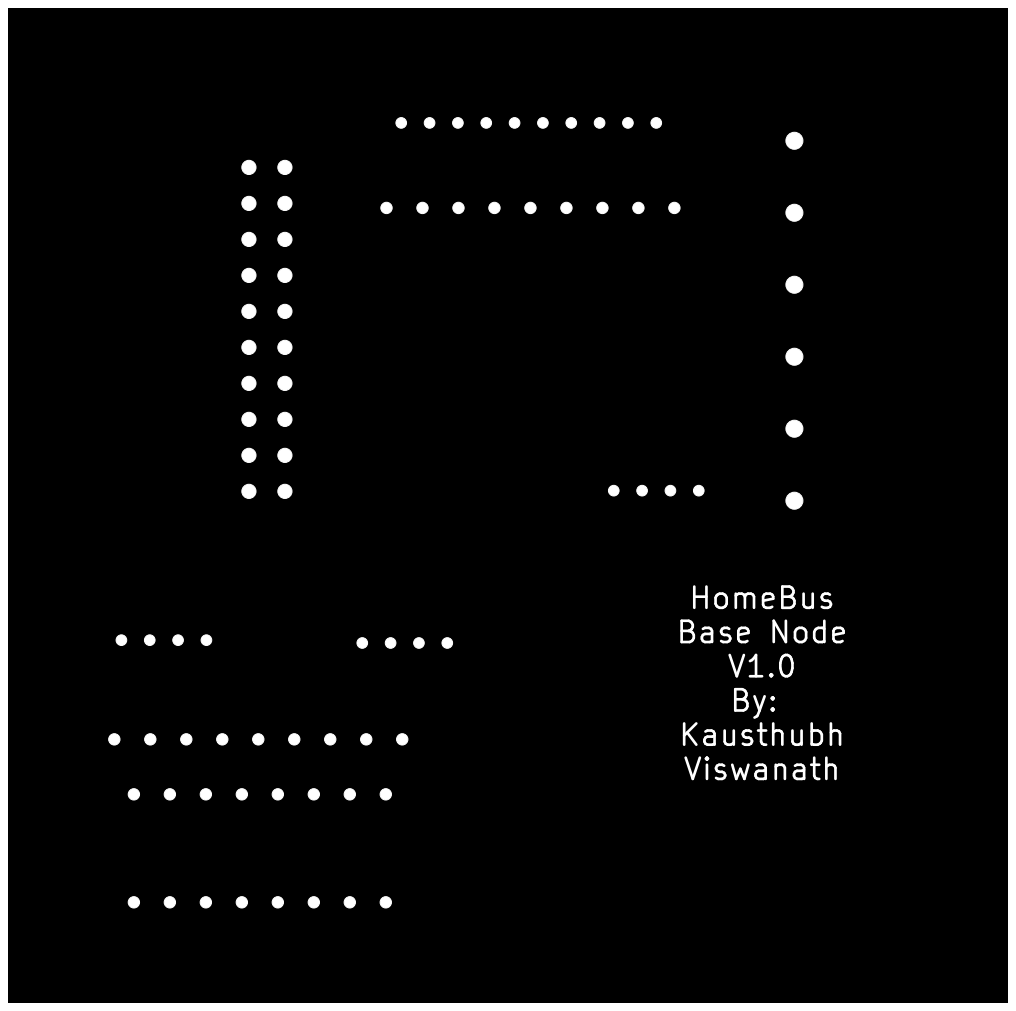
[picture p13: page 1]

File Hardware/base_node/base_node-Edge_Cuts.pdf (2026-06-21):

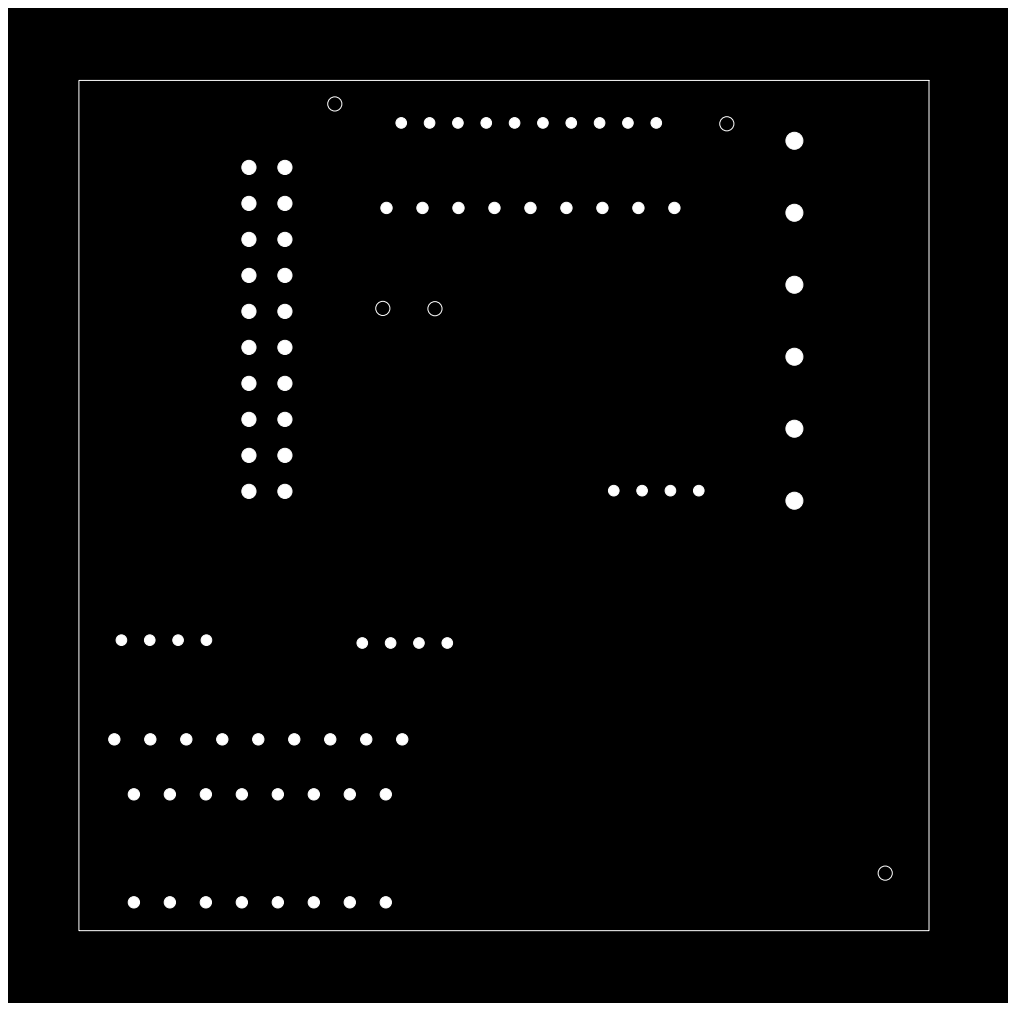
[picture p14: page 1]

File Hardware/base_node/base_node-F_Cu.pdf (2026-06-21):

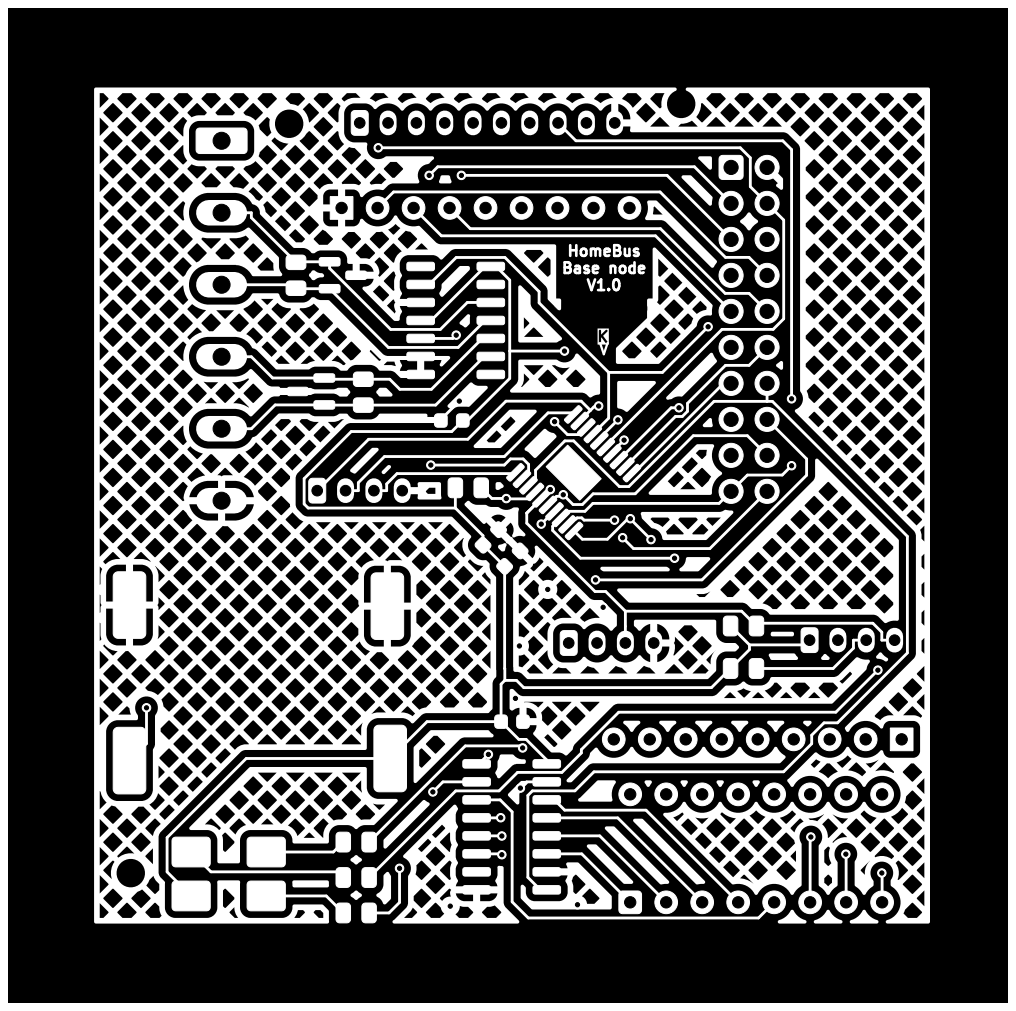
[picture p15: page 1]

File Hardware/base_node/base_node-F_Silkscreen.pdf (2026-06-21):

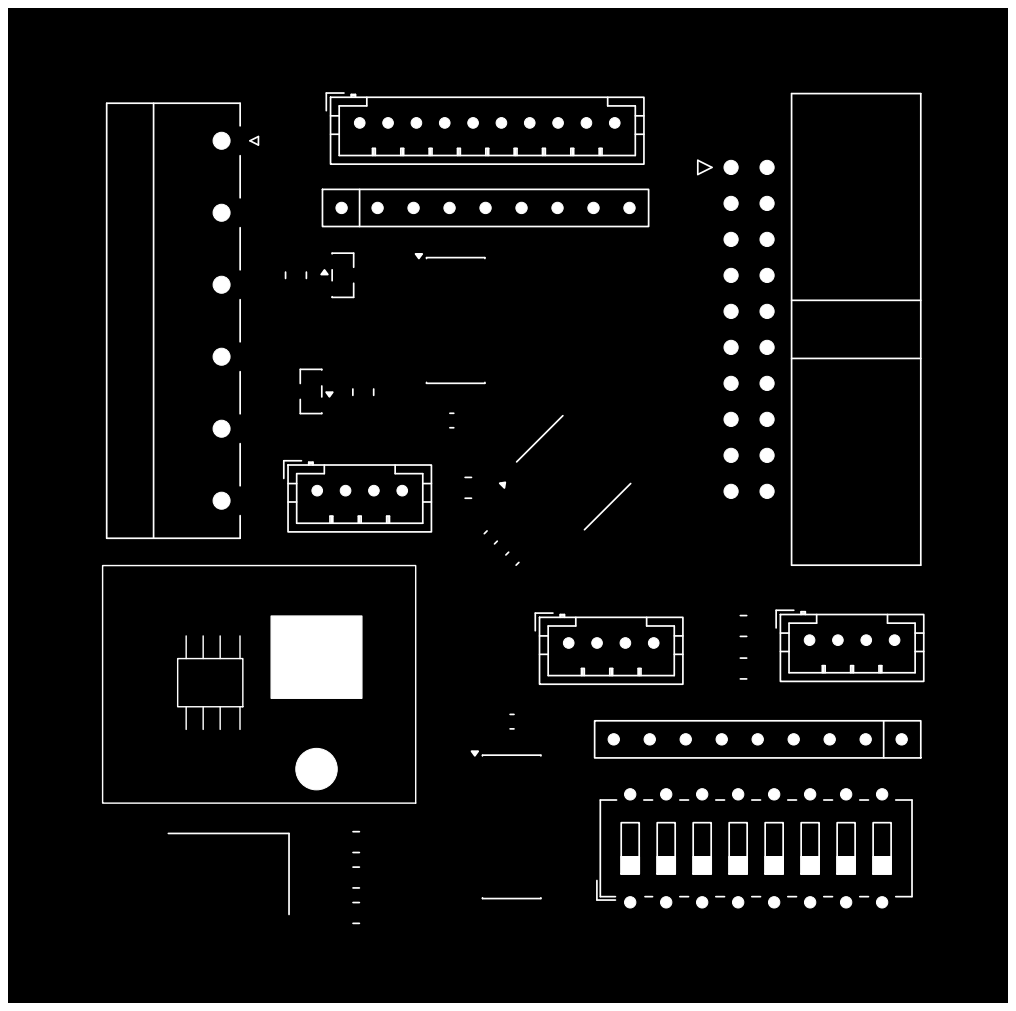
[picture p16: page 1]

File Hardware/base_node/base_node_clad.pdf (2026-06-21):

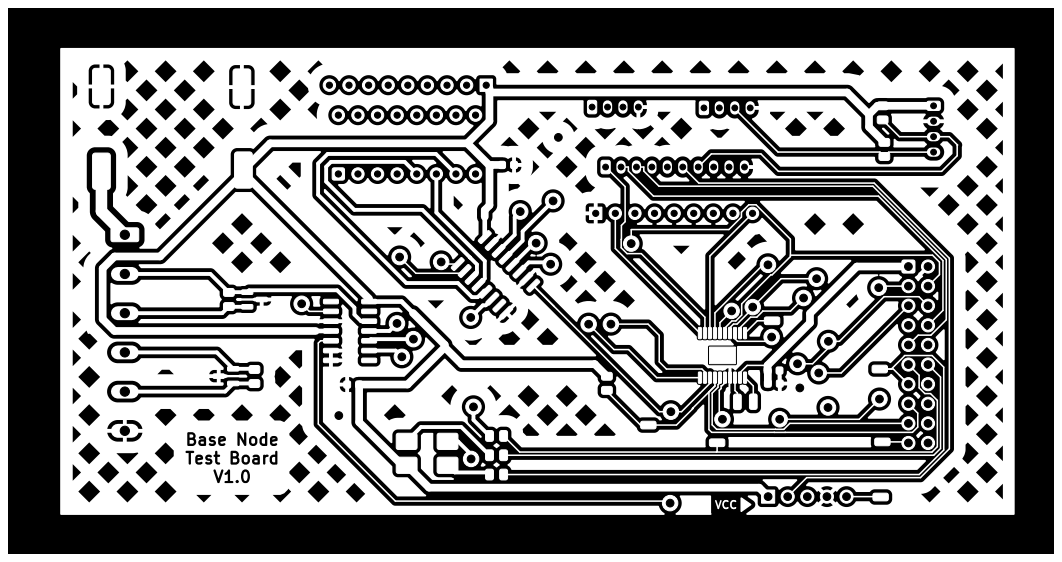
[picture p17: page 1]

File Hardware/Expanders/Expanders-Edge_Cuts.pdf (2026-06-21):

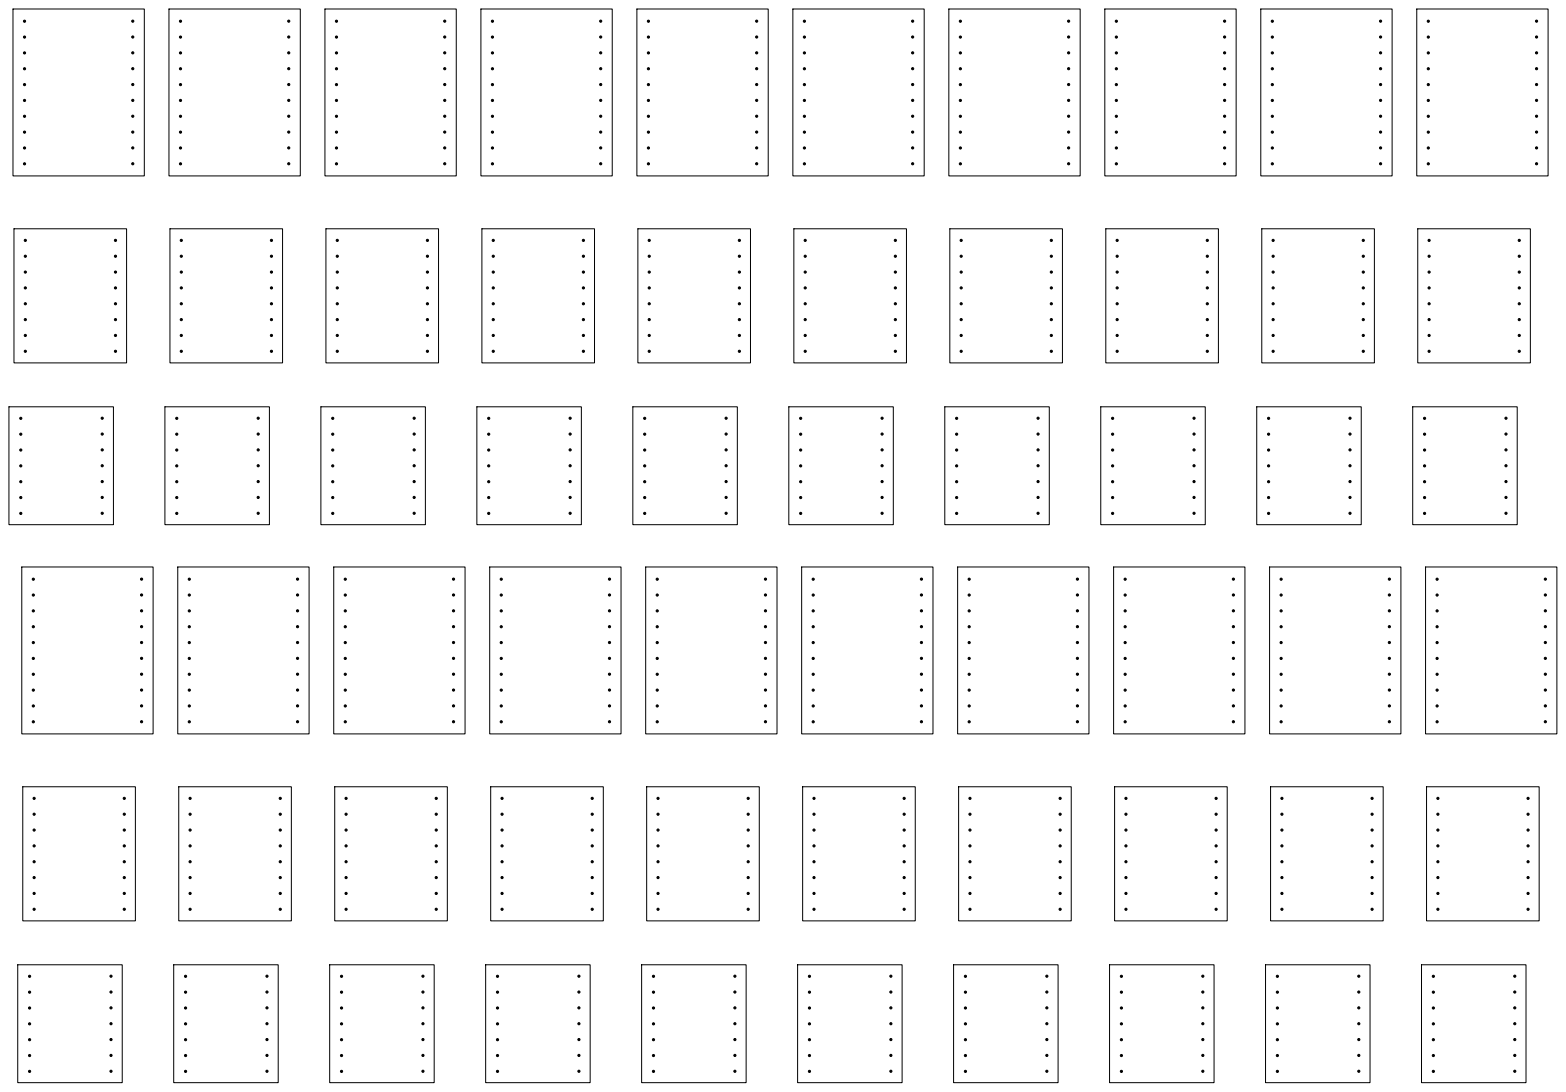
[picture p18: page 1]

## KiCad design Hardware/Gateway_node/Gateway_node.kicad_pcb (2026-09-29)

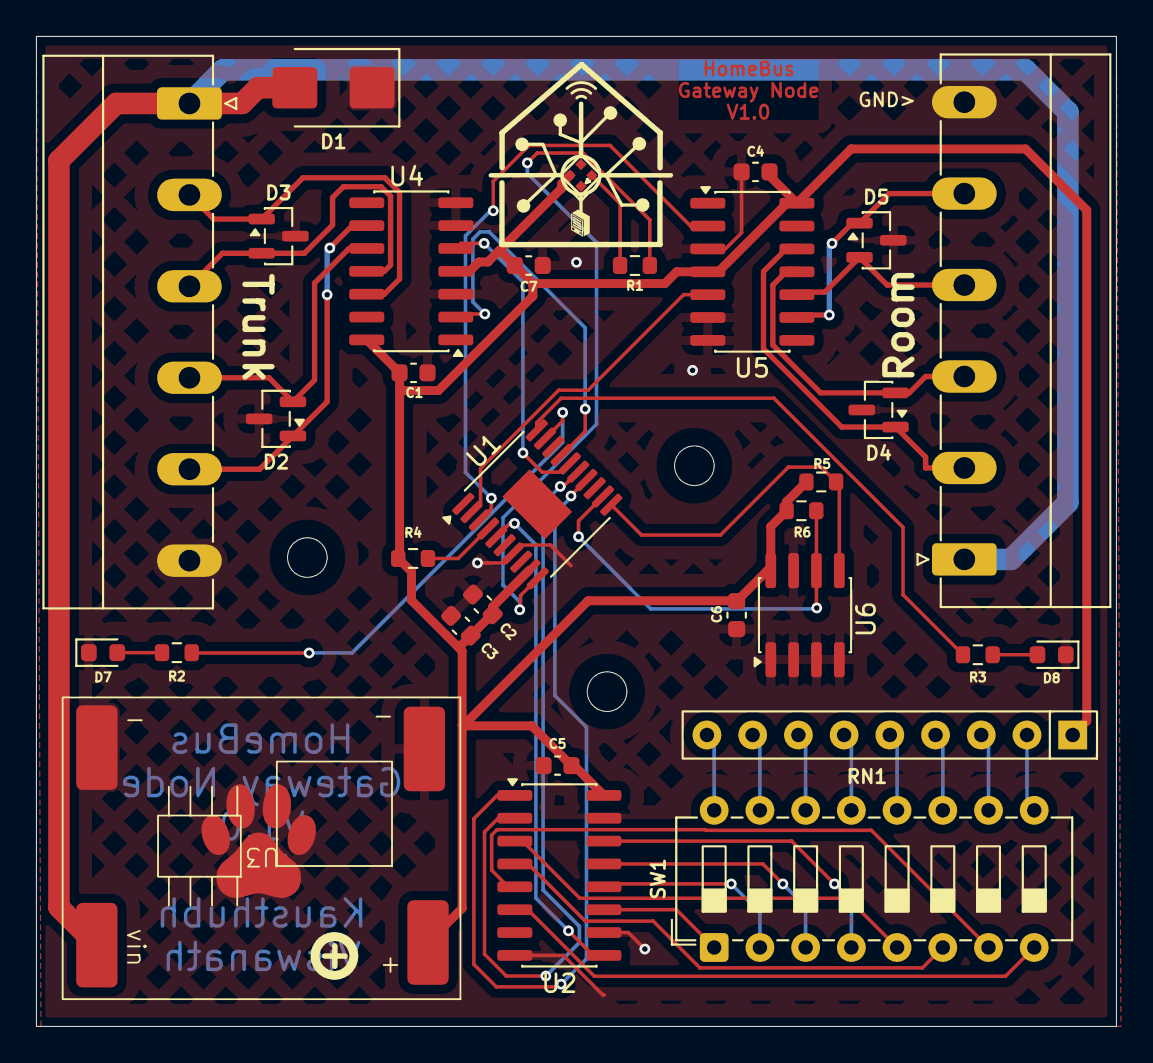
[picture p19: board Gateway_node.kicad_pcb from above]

Board: 2 copper layers, 60.0 x 55.0 mm, 32 parts (1 on the bottom side), 43 nets.

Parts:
C1, C2, C4, C5, C6, C7: 100nF; C_0603_1608Metric
C3: 10uF; C_0603_1608Metric
D1: D_TVS; D_SMB
D2, D3, D4, D5: SM712_SOT23; SOT-23
D6: WS2812B; XINGLIGHT-XL-1010RGBC-WS2812B
D7, D8: LED; LED_0603_1608Metric
J1: RS-422 Room; PhoenixContact_MC_1,5_6-G-5.08_1x06_P5.08mm_Horizontal
J2: RS-422 Trunk; PhoenixContact_MC_1,5_6-G-5.08_1x06_P5.08mm_Horizontal
Lg2: OSHW-Logo_5.7x6mm_SilkScreen
R1: 330Ω; R_0603_1608Metric
R2, R3: 10kΩ; R_0603_1608Metric
R4: 10KΩ; R_0603_1608Metric
R5, R6: 4.7kΩ; R_0603_1608Metric
RN1: 10KΩ; R_Array_SIP9
SW1: SW_DIP_x08; SW_DIP_SPSTx08_Slide_6.7x21.88mm_W7.62mm_P2.54mm_LowProfile
U1: CH32X033F8P6; TSSOP-20-1EP_4.4x6.5mm_P0.65mm_EP2.15x3.35mm
U2: 74HC165; SOIC-16_3.9x9.9mm_P1.27mm
U3: MP1584 Module
U4, U5: MAX491E; SOIC-14_3.9x8.7mm_P1.27mm
U6: AT24C256C-SSHL; SOIC-8_3.9x4.9mm_P1.27mm

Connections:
+5V: C1.2, C2.1, C3.1, C4.2, C5.1, C6.1, C7.2, D6.1 (VDD), R4.1, R5.2, R6.2, RN1.1 (common), U1.9 (Vdd), U2.16 (VCC), U3.3 (VOUT), U4.4 (DE), U4.14 (VCC), U5.4 (DE), U5.14 (VCC), U6.8 (VCC)
+24V: D1.2 (A2), J1.1, J2.1, U3.1 (VIN)
GND: C1.1, C2.2, C3.2, C4.1, C5.2, C6.2, C7.1, D1.1 (A1), D2.3 (common), D3.3 (common), D4.3 (common), D5.3 (common), D6.3 (VSS), D7.1 (K), D8.1 (K), J1.6, J2.6, U1.7 (GND), U2.8 (GND), U2.10 (DS), U2.15 (~CE), U3.2 (GND), U3.4 (GND), U4.3 (~RE), U4.6 (GND), U4.7 (GND), U5.3 (~RE), U5.6 (GND), U5.7 (GND), U6.1 (A0), U6.2 (A1), U6.3 (A2), U6.4 (GND), U6.7 (WP)
unnamed: D2.1 (A1), J2.5, U4.9 (Y)
unnamed: D2.2 (A2), J2.4, U4.10 (Z)
unnamed: D3.1 (A1), J2.2, U4.12 (A)
unnamed: D3.2 (A2), J2.3, U4.11 (B)
unnamed: D4.1 (A1), J1.2, U5.12 (A)
unnamed: D4.2 (A2), J1.3, U5.11 (B)
unnamed: D5.1 (A1), J1.5, U5.9 (Y)
unnamed: D5.2 (A2), J1.4, U5.10 (Z)
unnamed: D6.4 (DIN), R1.2
unnamed: D7.2 (A), R2.1
unnamed: D8.2 (A), R3.2
unnamed: RN1.2 (R1), SW1.9
unnamed: RN1.3 (R2), SW1.10
unnamed: RN1.4 (R3), SW1.11
unnamed: RN1.5 (R4), SW1.12
unnamed: RN1.6 (R5), SW1.13
unnamed: RN1.7 (R6), SW1.14
unnamed: RN1.8 (R7), SW1.15
unnamed: RN1.9 (R8), SW1.16
unnamed: U1.14 (PA0/A0), U2.1 (~PL)
unnamed: U1.15 (PA1/A1), U2.2 (CP)
unnamed: U1.16 (PA2/TX2), U4.5 (DI)
unnamed: U1.17 (PA3/RX2), U4.2 (RO)
unnamed: R2.2, U1.19 (PA4)
unnamed: R3.1, U1.20 (PA5)
unnamed: U1.2 (PA7/MOSI), U5.5 (DI)
unnamed: R1.1, U1.10 (PA9)
unnamed: R6.1, U1.12 (PA10/TX1/SCK), U6.6 (SCL)
unnamed: R5.1, U1.11 (PA11/RX1/SDA), U6.5 (SDA)
unnamed: U1.3 (PB1/A9), U5.2 (RO)
unnamed: R4.2, U1.4 (PB7/RST)
unnamed: U1.5 (PC16), U2.9 (Q7)
unnamed: SW1.1, U2.11 (D0)
unnamed: SW1.2, U2.12 (D1)
unnamed: SW1.3, U2.13 (D2)
unnamed: SW1.4, U2.14 (D3)
unnamed: SW1.5, U2.3 (D4)
unnamed: SW1.6, U2.4 (D5)
unnamed: SW1.7, U2.5 (D6)
unnamed: SW1.8, U2.6 (D7)

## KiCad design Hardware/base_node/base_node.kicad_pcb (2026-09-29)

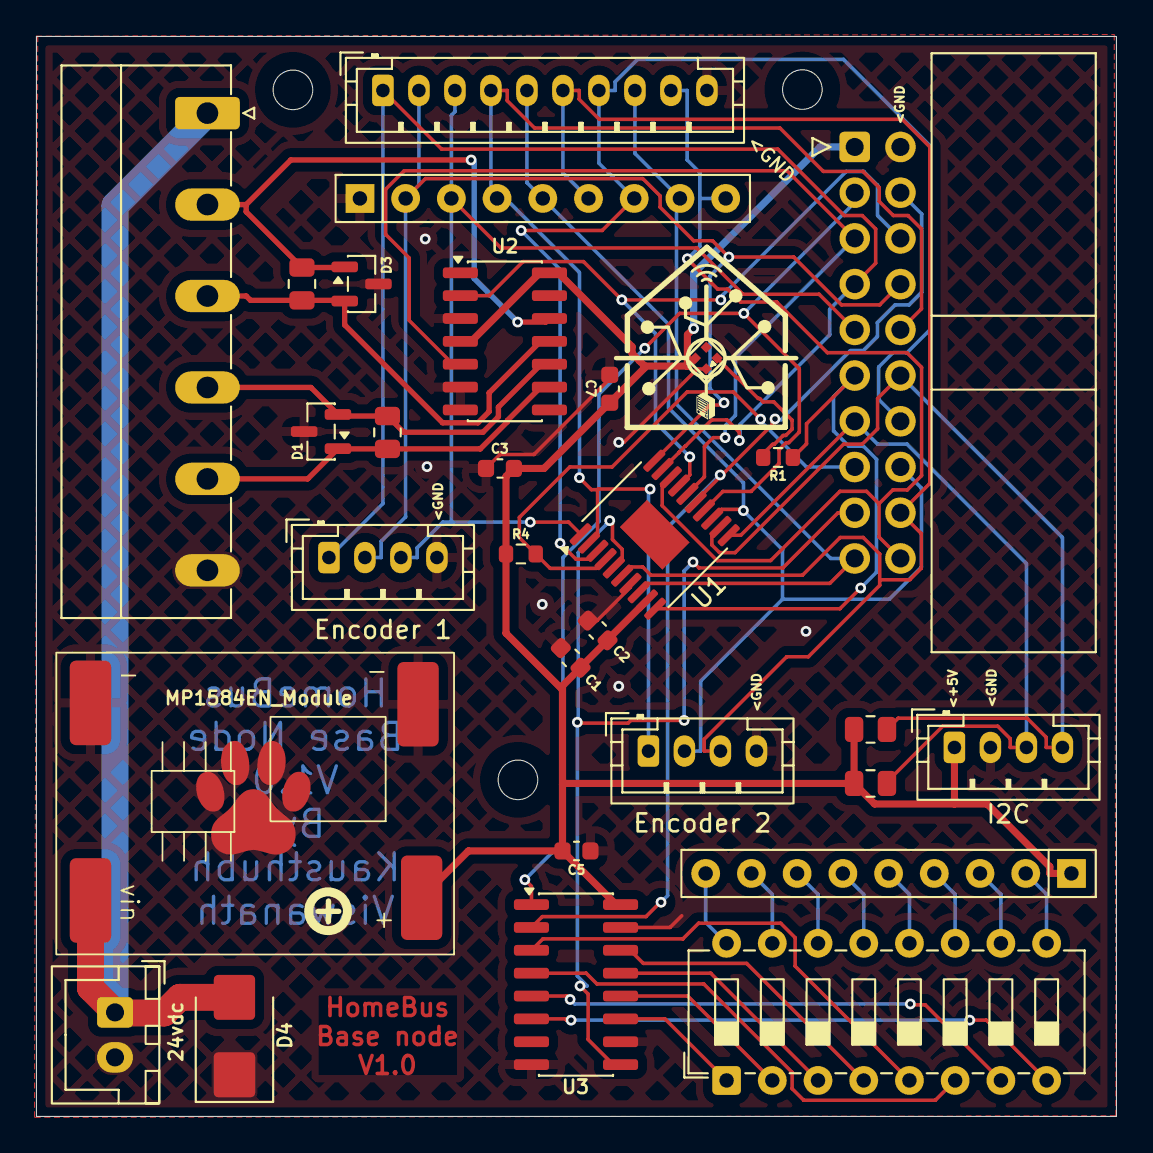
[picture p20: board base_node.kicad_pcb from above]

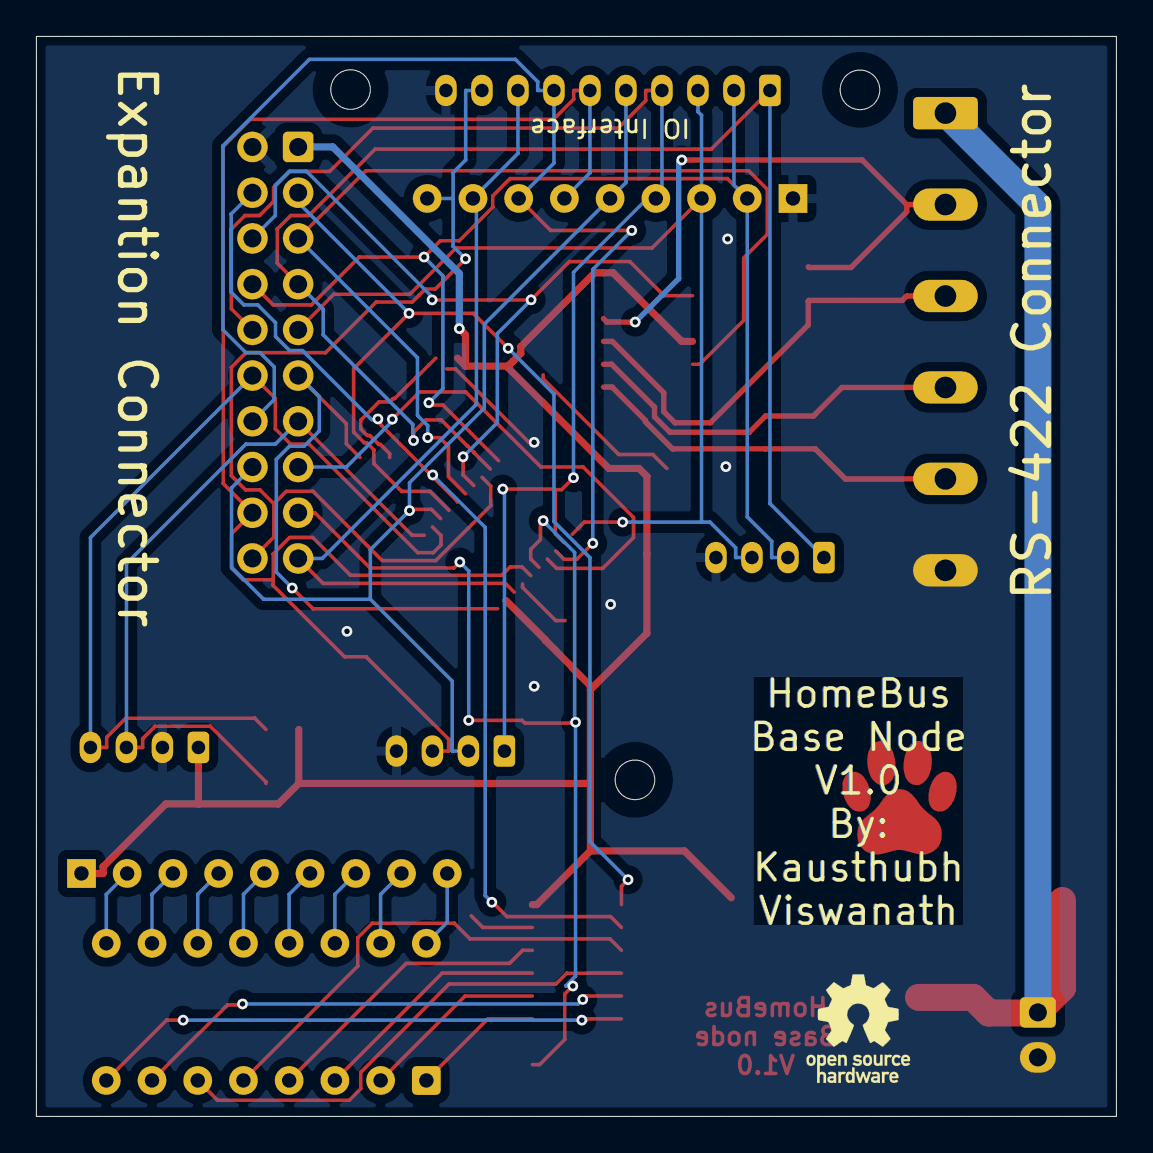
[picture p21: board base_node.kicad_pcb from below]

Board: 2 copper layers, 60.0 x 60.0 mm, 34 parts (4 on the bottom side), 42 nets.

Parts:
C1, C3, C5, C7: 100nF; C_0603_1608Metric
C2: 10uF; C_0603_1608Metric
D1, D3: SM712_SOT23; SOT-23
D2: WS2812B; XINGLIGHT-XL-1010RGBC-WS2812B
D4: SMBJ26A; D_SMB
J1: IO Interface; JST_PH_B10B-PH-K_1x10_P2.00mm_Vertical
J2: RS-422 Connector; PhoenixContact_MC_1,5_6-G-5.08_1x06_P5.08mm_Horizontal
J3: Expantion Connector; IDC-Header_2x10_P2.54mm_Horizontal
J4: I2C; JST_PH_B4B-PH-K_1x04_P2.00mm_Vertical
J5: 24vdc; JST_XH_B2B-XH-A_1x02_P2.50mm_Vertical
J6: Encoder 1; JST_PH_B4B-PH-K_1x04_P2.00mm_Vertical
J7: Encoder 2; JST_PH_B4B-PH-K_1x04_P2.00mm_Vertical
Lg1: HomeBus_LOGO
Lg2: OSHW-Logo_5.7x6mm_SilkScreen
Mount1, Mount2, Mount3: MountingHole_2.2mm_M2
R1: 330Ω; R_0603_1608Metric
R4: 10KΩ; R_0603_1608Metric
R5, R6: 120Ω; R_0805_2012Metric
R7, R8: 4.7kΩ; R_0805_2012Metric
RN1, RN2: 10KΩ; R_Array_SIP9
SW1: SW_DIP_x08; SW_DIP_SPSTx08_Slide_6.7x21.88mm_W7.62mm_P2.54mm_LowProfile
U1: CH32X033F8P6; TSSOP-20-1EP_4.4x6.5mm_P0.65mm_EP2.15x3.35mm
U2: MAX491E; SOIC-14_3.9x8.7mm_P1.27mm
U3: 74HC165; SOIC-16_3.9x9.9mm_P1.27mm
U4: MP1584EN_Module; MP1584 Module

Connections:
+5V: C1.1, C2.1, C3.2, C5.1, C7.2, D2.1 (VDD), J3.1, J4.1, R4.1, R7.1, R8.1, RN1.1 (common), U1.9 (Vdd), U2.4 (DE), U2.14 (VCC), U3.16 (VCC), U4.3 (VOUT)
/+24V: D4.2 (A2), J2.1, J5.1, U4.1 (VIN)
/RX+: D1.1 (A1), J2.5, R6.1, U2.9 (Y)
/RX-: D1.2 (A2), J2.4, R6.2, U2.10 (Z)
/SCL: J3.12, J4.4, R8.2, U1.12 (PA10/TX1/SCK)
/SDA: J3.13, J4.3, R7.2, U1.11 (PA11/RX1/SDA)
/TX+: D3.1 (A1), J2.2, R5.1, U2.12 (A)
/TX-: D3.2 (A2), J2.3, R5.2, U2.11 (B)
GND: C1.2, C2.2, C3.1, C5.2, C7.1, D1.3 (common), D2.3 (VSS), D3.3 (common), D4.1 (A1), J1.10, J2.6, J3.2, J4.2, J5.2, J6.4, J7.4, RN2.1 (common), U1.7 (GND), U2.3 (~RE), U2.6 (GND), U2.7 (GND), U3.8 (GND), U3.10 (DS), U3.15 (~CE), U4.2 (GND), U4.4 (GND)
unnamed: D2.4 (DIN), R1.2
unnamed: J1.1, J3.7, J6.1, U1.19 (PA4)
unnamed: J1.2, J3.8, J6.2, RN2.2 (R1), U1.20 (PA5)
unnamed: J1.3, J3.9, J6.3, RN2.3 (R2), U1.1 (PA6/MSIO)
unnamed: J1.4, J3.10, J7.1, RN2.4 (R3), U1.2 (PA7/MOSI)
unnamed: J1.5, J3.16, J7.2, RN2.5 (R4), U1.13 (PC3)
unnamed: J1.6, J3.18, J7.3, RN2.6 (R5), U1.6 (PC17)
unnamed: J1.7, J3.14, RN2.7 (R6), U1.3 (PB1/A9)
unnamed: J1.8, J3.19, RN2.8 (R7), U1.8 (USART3_TC)
unnamed: J1.9, J3.20, RN2.9 (R8), U1.18 (USART3_RX)
unnamed: J3.3, U1.14 (PA0/A0), U3.1 (~PL)
unnamed: J3.4, U1.15 (PA1/A1), U3.2 (CP)
unnamed: J3.5, U1.16 (PA2/TX2), U2.5 (DI)
unnamed: J3.6, U1.17 (PA3/RX2), U2.2 (RO)
unnamed: J3.11, R1.1, U1.10 (PA9)
unnamed: J3.15, R4.2, U1.4 (PB7/RST)
unnamed: J3.17, U1.5 (PC16), U3.9 (Q7)
unnamed: RN1.2 (R1), SW1.9
unnamed: RN1.3 (R2), SW1.10
unnamed: RN1.4 (R3), SW1.11
unnamed: RN1.5 (R4), SW1.12
unnamed: RN1.6 (R5), SW1.13
unnamed: RN1.7 (R6), SW1.14
unnamed: RN1.8 (R7), SW1.15
unnamed: RN1.9 (R8), SW1.16
unnamed: SW1.1, U3.11 (D0)
unnamed: SW1.2, U3.12 (D1)
unnamed: SW1.3, U3.13 (D2)
unnamed: SW1.4, U3.14 (D3)
unnamed: SW1.5, U3.3 (D4)
unnamed: SW1.6, U3.4 (D5)
unnamed: SW1.7, U3.5 (D6)
unnamed: SW1.8, U3.6 (D7)

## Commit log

2026-06-21 Initial HomeBus commit
    [Expanders.kicad_pcb, Expanders.kicad_sch, MOS_Fan_Controller_Hat.kicad_pcb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]
2026-06-21 Remove KiCad temporary files
2026-09-29 docs: establish hierarchical documentation structure and subsystem guides
    - Created root navigation hub README.md linking architecture, subsystems, and components
    - Added Hardware Subsystem README (bus topology, 24V power rail, RS-422, SM712 protection, BOM)
    - Created Base Node README with pinouts (Dev vs Prod), 3D production renders, and manufacturing specs
    - Created Gateway Node README with dual-transceiver room segmentation, EEPROM routing, and dev board
    - Created Fan Controller Node README with ZCD optocoupler, isolated gate drive, and anti-stall logic
    - Created Expanders README with SMD breakout adapter specs and layout previews
    - Created Firmware & Protocol Specification README coverin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
    [BOM Home automation.xlsx, Fan_Controller_node.kicad_pcb, Fan_Controller_node.kicad_sch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]
